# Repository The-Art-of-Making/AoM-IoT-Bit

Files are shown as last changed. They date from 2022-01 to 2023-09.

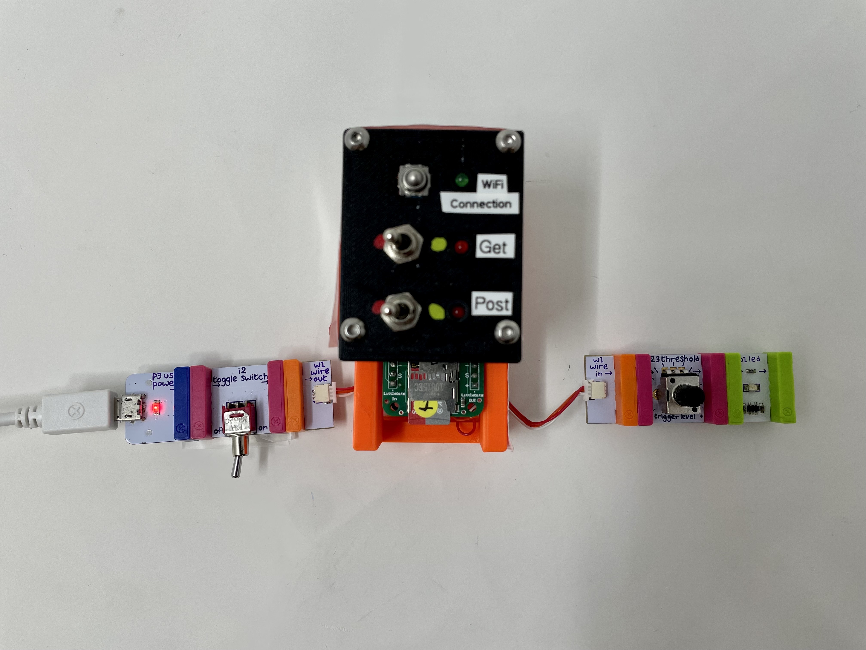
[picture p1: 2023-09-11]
Diagrams/quick-start-guide_circuit.jpg

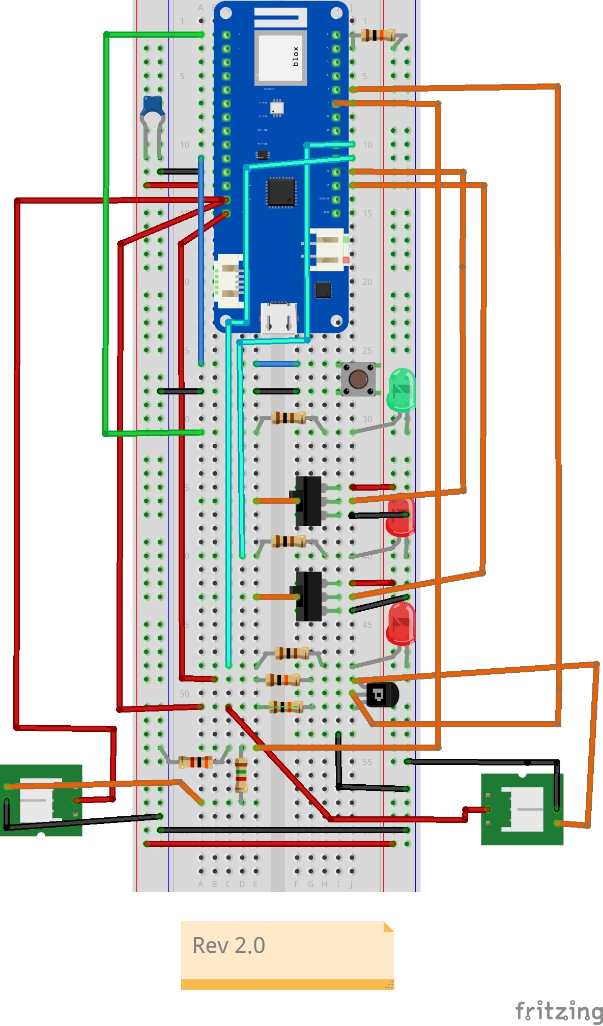
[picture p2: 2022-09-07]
Fritzing-Schematics-PCB/AOM_IoT_Bit_V3.0_breadboard.jpg

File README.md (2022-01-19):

# AOM IoT Bit - Spring 2022
------------------------------------

## Summary
------------------------------------
The AOM IoT Bit, is a device that allows students to prototype with IoT, without the overhead of all the logistics that come with setup.

The goal is that students will be able to **easily link an AOM IoT Bit to a LittleBits circuit, and get that circuit to send and/or recieve data through a cloud-based system**.

**\*\*Insert Image Here\*\***

------------------------------------
## Usage of a fully setup AOM IoT Bit
------------------------------------
To Use the AOM IoT Bit, all a student needs to do is the following:

- Open up a serial connection and ... add their credentials to the arduino_secrets_mine.h file ***[DO NOT SHARE THIS!]***

- Push the code to the MKR 1010 Arduino Board.

- Plug it in to their LittleBits circuit, and set the onboard switch to the proper setting (Push, Poll, Both)

------------------------------------
## Building an AOM IoT Bit
------------------------------------
We have started by using the Arduino MKR 1010 Board, Found Here:
**\*\*Insert Build Instructions Here\*\***

------------------------------------
## Initial Setup of an AOM IoT Bit
------------------------------------
**\*\*Insert Setup Instructions Here\*\***

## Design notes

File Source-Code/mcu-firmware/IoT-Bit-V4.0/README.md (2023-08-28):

# IoT-Bit-V4.0 Firmware

Arduino-based firmware for connecting the IoT Bit to an MQTT server.

Target board: Arduino MKR WiFi 1010

## Overview

1. Wifi and MQTT authentication credentials are read from the SD card.
2. The Bit connects to Wifi.
3. If a Wifi connection is established, the Bit then tries to connect to a MQTT server, authenticate, and subscribe to the `config` and `cmd` topics corresponding to its devices.
4. The Bit configures its devices based on the configuration received on the `config` topics. Configurations information is stored in protocol buffers sent in the payload of MQTT messages published to the `config` topics.
5. The Bit publishes messages with the value of its input devices to the `state` topics whenever the values of the input devices change. The Bit also updates its output devices whenever it receives a message with an updated output value on the `cmd` topics.

## Prerequisites

1. Arduino `WiFiNINA` and `Ethernet` libraries

2. PubSubClient library for Arduino

   See [https://github.com/knolleary/pubsubclient](https://github.com/knolleary/pubsubclient)

3. nanopb and protoc (Optional)

   The `compile_protobufs.sh` script found in the `Source-Code/Backend/protobufs` directory can be used to automatically compile the necessary proto files. While technically only nanopb (which ships with this respository) is needed to generate the C implementation of the protocol buffers used in the firmware, the script generates the implementations for both C and python, and therefore also depends on protoc to run correctly in its current form. If you do not wish to install protoc or wish to compile the proto files manually, you may do so solely with nanopb.

## Build

1. Compile the proto files found in `Source-Code/Backend/protobufs` using nanopb
2. Open `IoT-Bit-V4.0.ino` in the Arduino IDE
3. Connect the IoT Bit and select the correct Board (Arduino MKR WiFi 1010) and Port
4. Click the "Upload" button to compile the firmware and upload it to the board

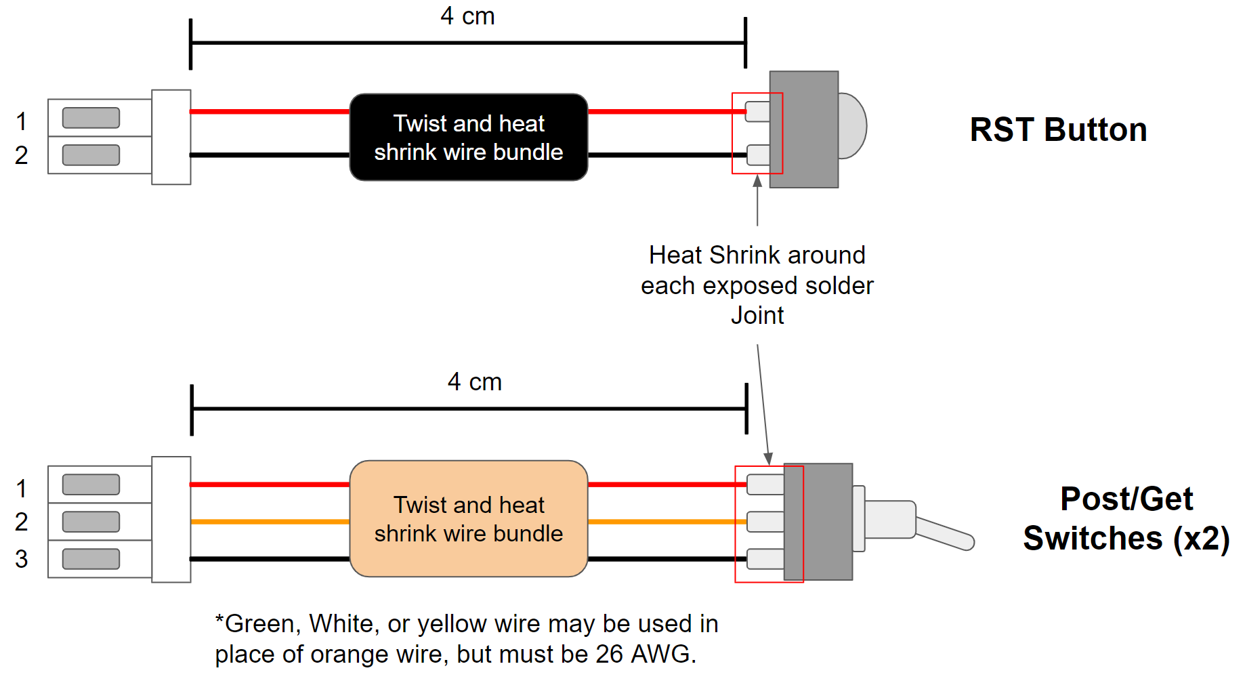
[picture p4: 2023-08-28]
media/REV_3/cable-diagram_button-switch.png

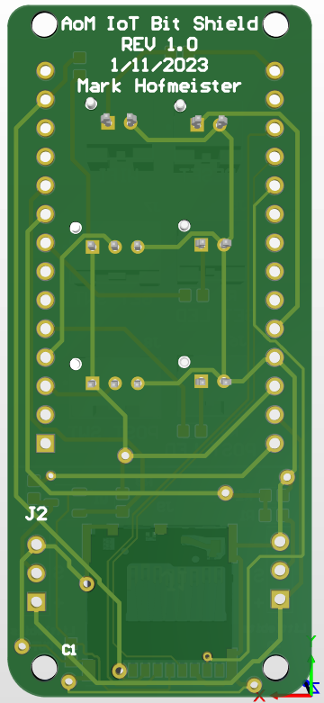
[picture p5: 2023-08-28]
media/REV_3/pcb-v1-bottom.png

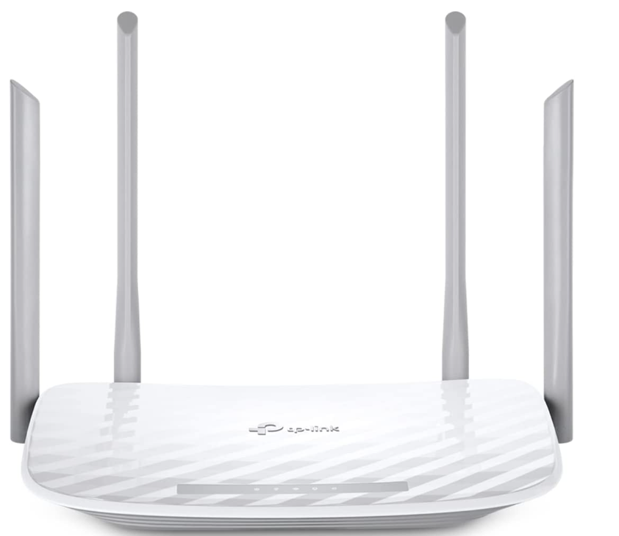
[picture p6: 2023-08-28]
media/REV_3/router.png

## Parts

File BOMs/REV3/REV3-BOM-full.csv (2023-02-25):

Name/Desc | MFR | MFR P/N | QTY | Vendor Link
Arduino MKR WiFi 1010 | Arduino | ABX00023 | 1 | https://store-usa.arduino.cc/products/arduino-mkr-wifi-1010
SD, LED, Switch PCB Shield | JLCPCB | - | 1 | https://jlcpcb.com/
Littlebits Wire | Sphero | 650-0071 | 1 | https://sphero.com/products/wire-bit
1x14 male headers | Lystaii | - | 2 | https://www.amazon.com/dp/B06ZZN8L9S
1x3 male headers | Lystaii | - | 2 | https://www.amazon.com/dp/B06ZZN8L9S
JST PA 2POS Male connector, TH | JST | B02B-PASK(LF)(SN) | 4 | https://www.digikey.com/en/products/detail/jst-sales-america-inc/B02B-PASK-1-LF-SN/926738
JST PA 2POS Female connector, TH | JST | PAP-02V-S | 4 | https://www.digikey.com/en/products/detail/jst-sales-america-inc/PAP-02V-S/759974
JST PA 3POS Male connector, TH | JST | B03B-PASK-1(LF)(SN) | 2 | https://www.digikey.com/en/products/detail/jst-sales-america-inc/B03B-PASK-1-LF-SN/926739
JST PA 3POS Female connector, TH | JST | PAP-03V-S | 2 | https://www.digikey.com/en/products/detail/jst-sales-america-inc/PAP-03V-S/759975
JST PA Crimps | JST | SPHD-002T-P0.5 | 14 | https://www.digikey.com/en/products/detail/jst-sales-america-inc/SPHD-002T-P0-5/608754
Red LED, 3mm | Adafruit | 777 | 2 | https://www.adafruit.com/product/777
Green LED, 3mm | Adafruit | 779 | 1 | https://www.adafruit.com/product/779
Metal tactile switch | Adafruit | 3347 | 1 | https://www.adafruit.com/product/3347
Plastic Beveled LED Holders | Adafruit | 2179 | 4 | https://www.adafruit.com/product/2179
SPDT Toggle Switch, Panel Mount | Adafruit | 3221 | 2 | https://www.adafruit.com/product/3221
M3 Knurled Threaded Inserts | SAVITA | - | 4 | https://www.amazon.com/dp/B0BMVHYGWM
M3 x 8mm Machine Screws | PZRT | - | 4 | https://www.amazon.com/dp/B07F6YGHKP
26 AWG Wire, Stranded Core, Red | OMEGA | 1569-26-1-0500-004-1-TS | 6 | https://www.digikey.com/en/products/detail/cnc-tech/1569-26-1-0500-004-1-TS/15853684
26 AWG Wire, Stranded Core, Black | OMEGA | 1569-26-1-0500-001-1-TS | 6 | https://www.digikey.com/en/products/detail/cnc-tech/1569-26-1-0500-001-1-TS/15853661
26 AWG Wire, Stranded Core, Yellow | OMEGA | 1569-26-1-0500-003-1-TS | 2 | https://www.digikey.com/en/products/detail/cnc-tech/1569-26-1-0500-003-1-TS/15853701
Heat shrink, red | - | - | 6 | -
Heat shrink, black | - | - | 6 | -
Heat shrink, yellow | - | - | 2 | -
microSD card, 8GB | Gigastone | - | 1 | https://www.amazon.com/dp/B0876H387X/
Paper-printed Decals, QR Code | - | - | 1 | -

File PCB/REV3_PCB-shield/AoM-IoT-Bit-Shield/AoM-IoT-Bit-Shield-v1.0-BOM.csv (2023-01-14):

Comment | Designator | Footprint | JLCPCB Part #?optional?
100 | R5,R7,R8 | 603 | C22775
10k | R3,R4,R6 | 603 | C25804
4.7k | R1 | 603 | C23162
9.1k | R2 | 603 | C23260
npn SOT-23-3 | Q1 | SOT-23-3 | C8512
sd slot | J9 | SMD | C428492
10uF | C1 | 603 | C19702

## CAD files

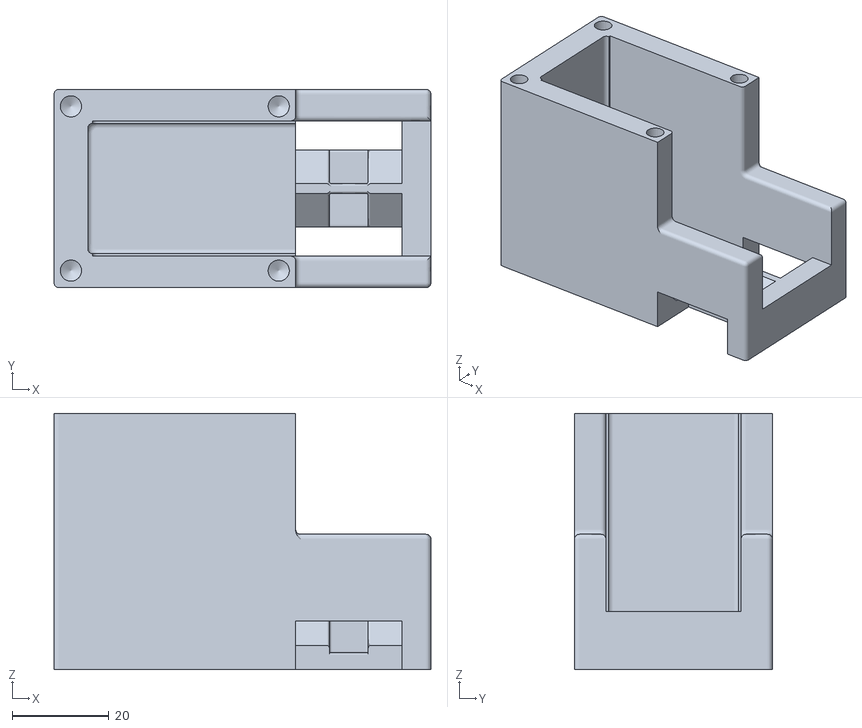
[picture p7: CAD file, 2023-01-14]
CAD/Base-Plate-v6.stl
78.0 x 41.0 x 53.0

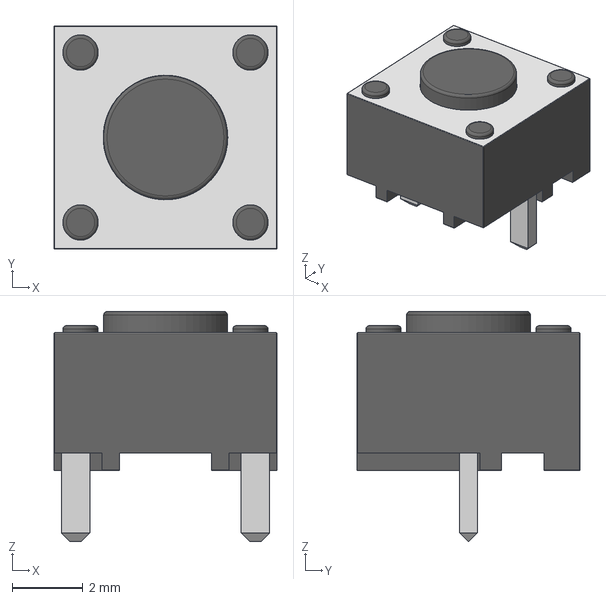
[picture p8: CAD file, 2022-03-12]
CAD/imported/Button black standard.STEP
6.30 x 6.30 x 6.50 mm

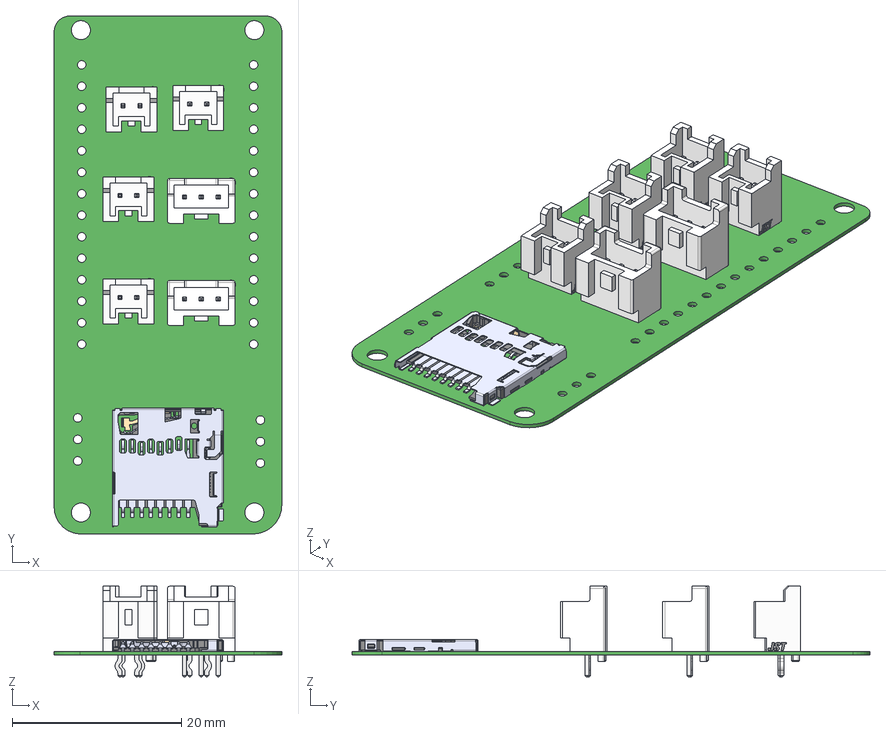
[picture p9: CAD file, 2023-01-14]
PCB/REV3_PCB-shield/AoM-IoT-Bit-Shield/AoM-IoT-Bit-Shield-v1.0.step
26.9 x 61.2 x 10.7 mm
B03B-PASK-1 x 2
JST Logo adjustable x 2
B02B-PASK-1 x 4

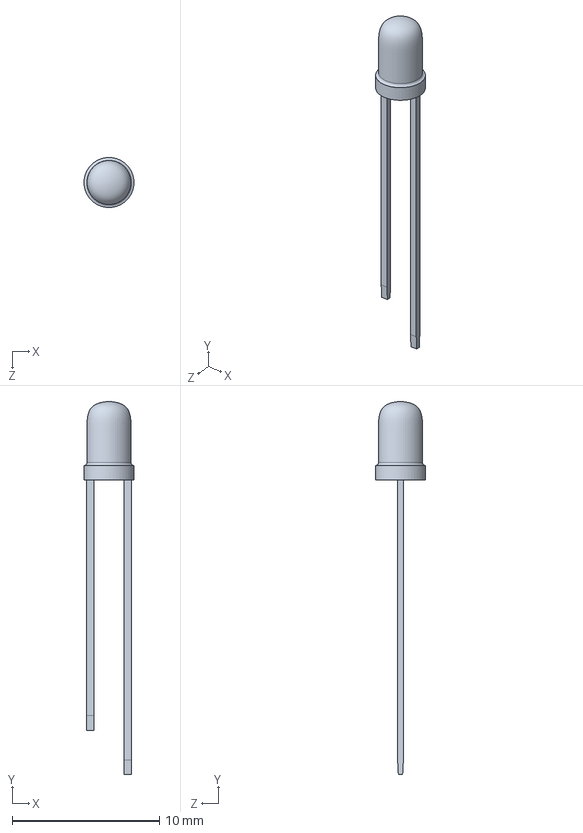
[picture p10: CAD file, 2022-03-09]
CAD/imported/redLED.SLDPRT
3.40 x 25.4 x 3.40 mm

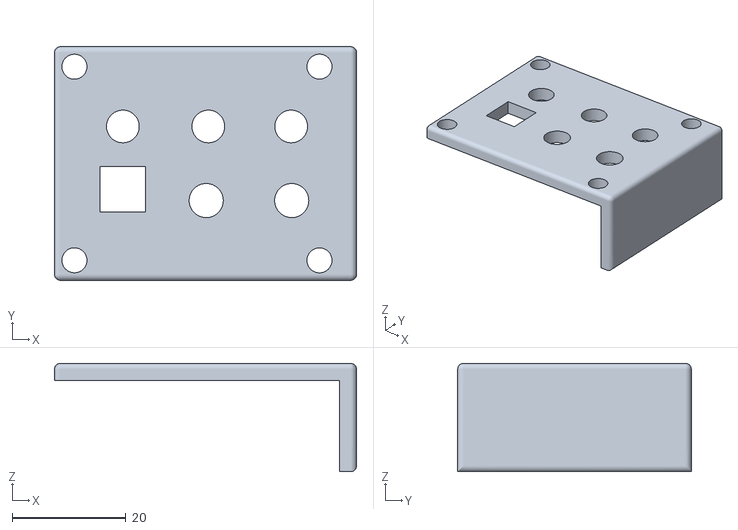
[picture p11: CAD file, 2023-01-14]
CAD/Top-plate-v7.stl
53.0 x 41.0 x 19.0

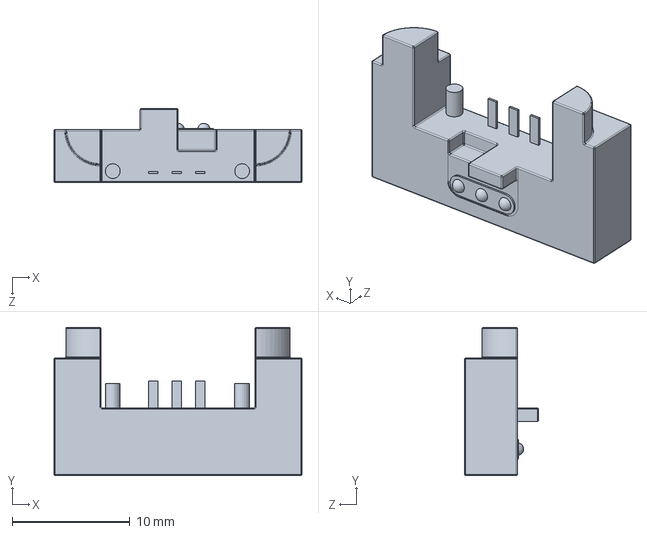
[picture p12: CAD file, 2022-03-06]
CAD/imported/Bit_1.SLDPRT
21.1 x 12.6 x 6.30 mm

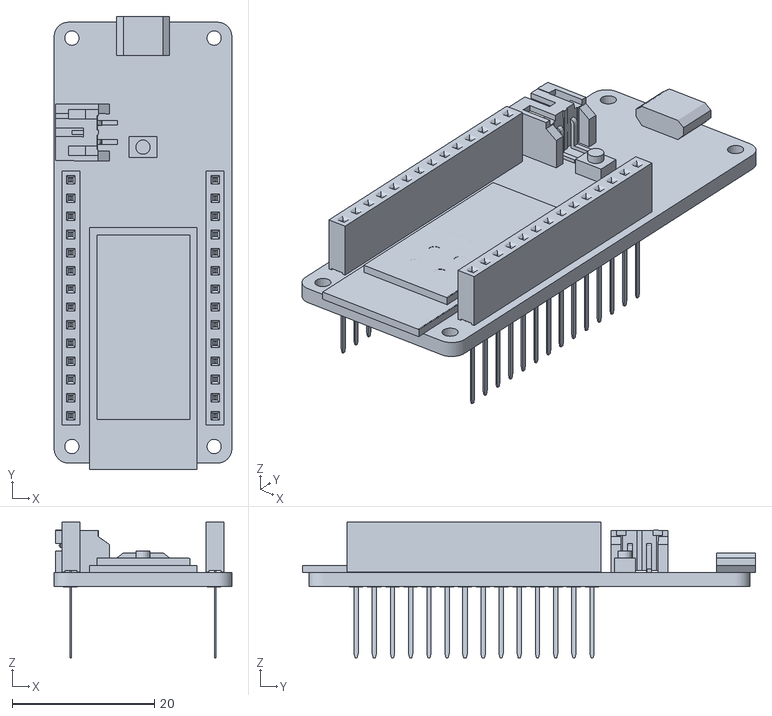
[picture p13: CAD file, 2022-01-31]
CAD/imported/Arduino_MKR_1000_long_pins.stl
25.0 x 63.7 x 19.1

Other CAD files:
CAD/imported/blueLED.SLDPRT
CAD/imported/Vertical slide switch SS-12D00G3 High Knob 3mm SPDT v2.f3d

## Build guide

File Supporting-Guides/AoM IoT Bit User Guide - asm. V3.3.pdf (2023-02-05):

# AoM IoT Bit User Guide

Author: Mark Hofmeister, (716) 261-0079, mah473@pitt.edu

Assembly v2.1, Electronics v2.1, Code v3.2

Last modified: 1/31/2023

You’ve just picked up one of the most sophisticated and useful LittleBits in the AoM repository of snap electronics. You’ve made a fantastic decision. This is the opportunity of a lifetime – and this video will show you why. (https://www.youtube.com/watch?v=zpKmXY5P1bY) Below will detail how to make the IoT bit come to life and a few basic example applications.

The IoT bit can either upload (“post”) or download (“get”) digital values from a cloud on the web. This means that it will be posting/getting values that are either HIGH or LOW, i.e. ON or OFF. This means that the Littlebits that you connect to the IoT Bit should be operated digitally. For example, you will be able to turn an LED ON or OFF with IoT bit. You will not, however, be able to adjust the brightness of the LED with a PWM signal. This means that you may need to make use of the “threshold” (https://classroom.littlebits.com/bit-o-pedia/threshold) and “latch” (https://classroom.littlebits.com/bit-o-pedia/latch) to digitize analog signals, which can be explored both through the links and through hands-on experimentation.

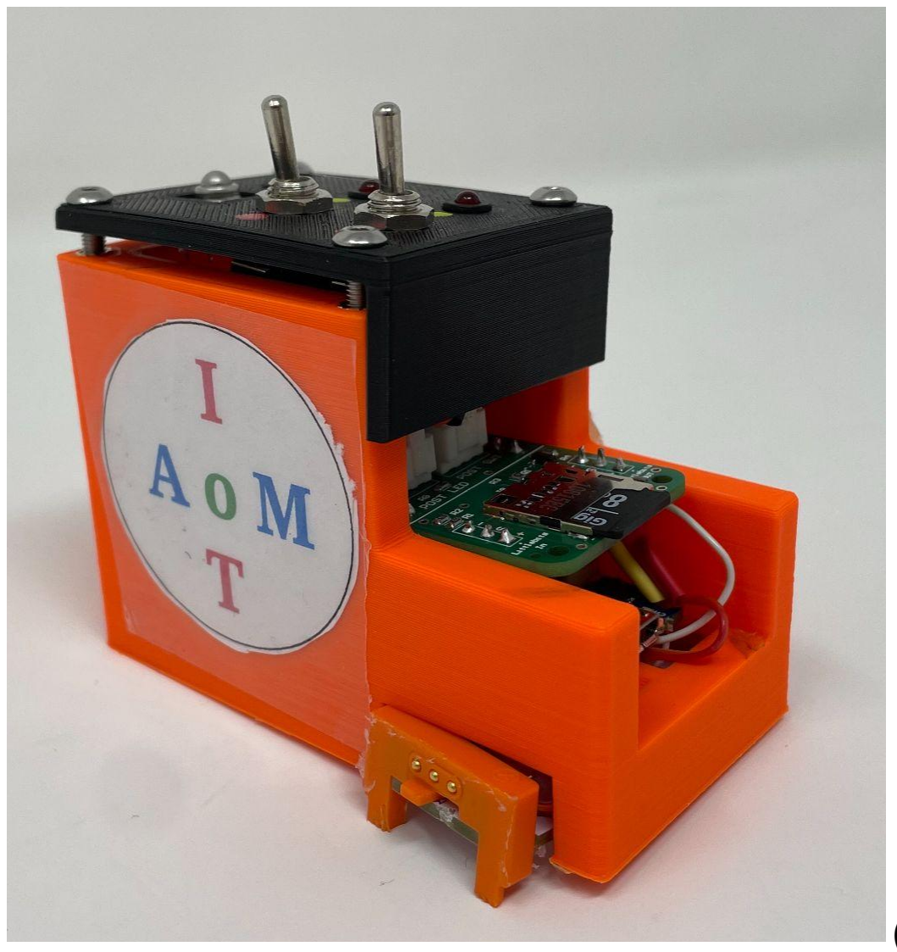
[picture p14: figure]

(Color may vary)

ENGR 0716/1716 The Art of Making: Hands-On System Design and Engineering • Version 3.2 | 1

## Table of Contents

## How Do I Use this Thing? How Do I Connect to IFTTT? Changing WiFi Credentials Windows Users Mac Users Changing an IoT Bit’s Feed Windows Users Mac Users “Hello, World” Applications 1. Post to IO 2. Get from IO Advanced Settings Using a different Adafruit IO+ account

ENGR 0716/1716 The Art of Making: Hands-On System Design and Engineering • Version 3.2 | 2

## How Do I Use this Thing?

Good question.

## Here’s a diagram of the interface’s functionality:

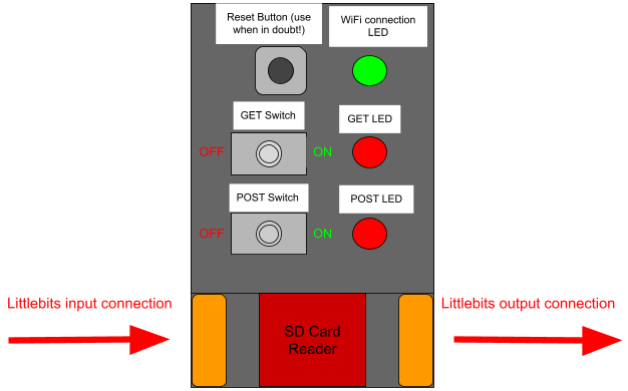
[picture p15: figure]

When you snap your IoT bit in series with (powered) Littlebits, you’ll see the IoT bit configure itself through these steps:
1. All 3 LEDs will blink 3 times quickly - This indicates that the IoT bit is going to attempt to read from the SD card. This flashing will repeat every ~3 seconds until the IoT Bit reads the SD card’s data successfully. If the flashing keeps repeating, make sure the SD card is seated in the SD card reader properly.
2. All 3 LEDs will blink for a full second - This indicates that the IoT bit has successfully read from the SD card and is ready to connect to the cloud.
3. The Green LED illuminates (and stays illuminated) - This indicates a successful WiFi connection. Be patient when connecting to WiFi - a secure connection can take ~10 seconds to establish.
ENGR 0716/1716 The Art of Making: Hands-On System Design and Engineering • Version 3.2 | 3

4. From here, the IoT bit will enter a loop depending on the state of the switches. Below are the 4 operations:
a. No switches are turned on - IoT Bit will remain idle and do nothing.
b. The GET Switch is turned on - The IoT Bit will “get” the latest value from the cloud. If the latest value in the cloud is “HIGH,” the IoT bit will output a HIGH electrical signal. If the latest value in the cloud is “LOW,” the IoT bit will output a LOW electrical signal.
c. The POST Switch is turned on - If the IoT Bit detects a change in the state of the digital input signal, it will “post” it to the cloud. If the IoT Bit’s electrical input signal value changes to “HIGH,” the IoT bit will post a HIGH value to the cloud. If the IoT Bit’s electrical input signal value changes to “LOW,” the IoT bit will post a LOW value to the cloud.
d. The GET switch and POST switch are both turned on - the IoT bit will both POST a changing incoming signal to Adafruit IO and GET the signal back from the cloud. Use this if you want to upload a value to the cloud as well as send that signal through the IoT bit to sequential LittleBits.
5. Log in to the AoM Cloud (https://io.adafruit.com/aom_cloud/feeds) and select the feed that your IoT Bit is connected to to view the latest data!
AoM Cloud Username: aom_cloud
AoM Cloud Password: designthinking

Do not hit “regenerate key” in Adafruit IO - this will change the access code and all IoT Bits will have to be reconfigured.

Again, be patient when connecting to WiFi - a secure connection (indicated by the illuminated green LED on the IoT Bit) can take ~10 seconds to establish.

ENGR 0716/1716 The Art of Making: Hands-On System Design and Engineering • Version 3.2 | 4

## How Do I Connect to IFTTT?

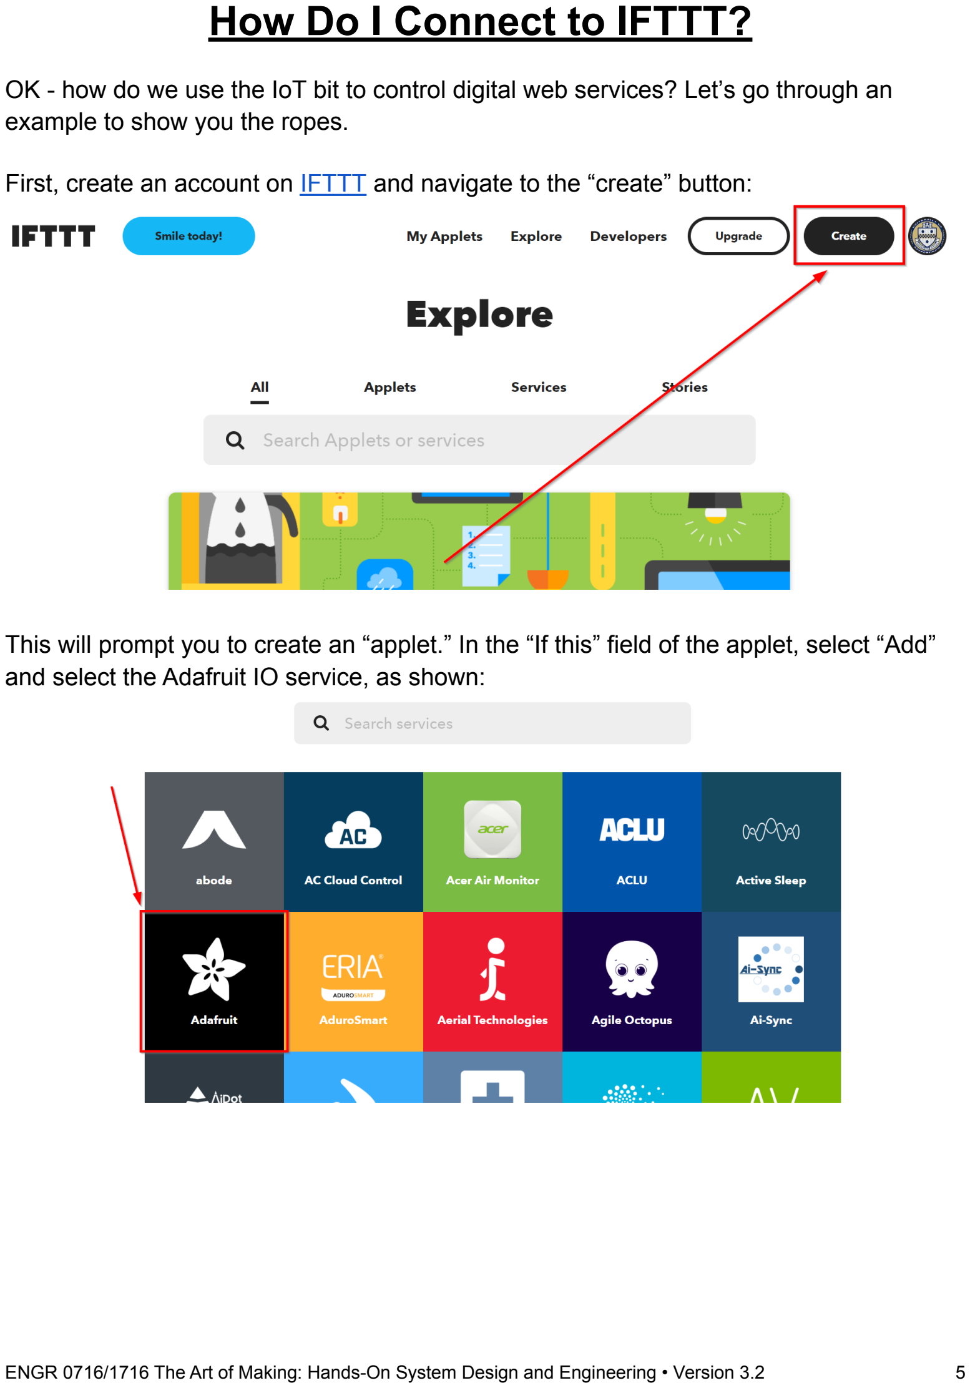
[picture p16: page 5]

OK - how do we use the IoT bit to control digital web services? Let’s go through an example to show you the ropes.

First, create an account on IFTTT (https://ifttt.com/join) and navigate to the “create” button:

This will prompt you to create an “applet.” In the “If this” field of the applet, select “Add” and select the Adafruit IO service, as shown:

ENGR 0716/1716 The Art of Making: Hands-On System Design and Engineering • Version 3.2 | 5

Authorize the sign-in prompt on IFTTT and select “Monitor a feed on Adafruit IO” as your trigger. Add the AoM Cloud’s Adafruit IO account name ( AoM IoT Bit,) AoM Cloud’s feed name (cloud - Feed {X}), set the relationship as “equal to,” and select “HIGH” as the value. This will trigger the “If this” portion of the widget any time the IoT bit uploads a HIGH value to Adafruit IO.

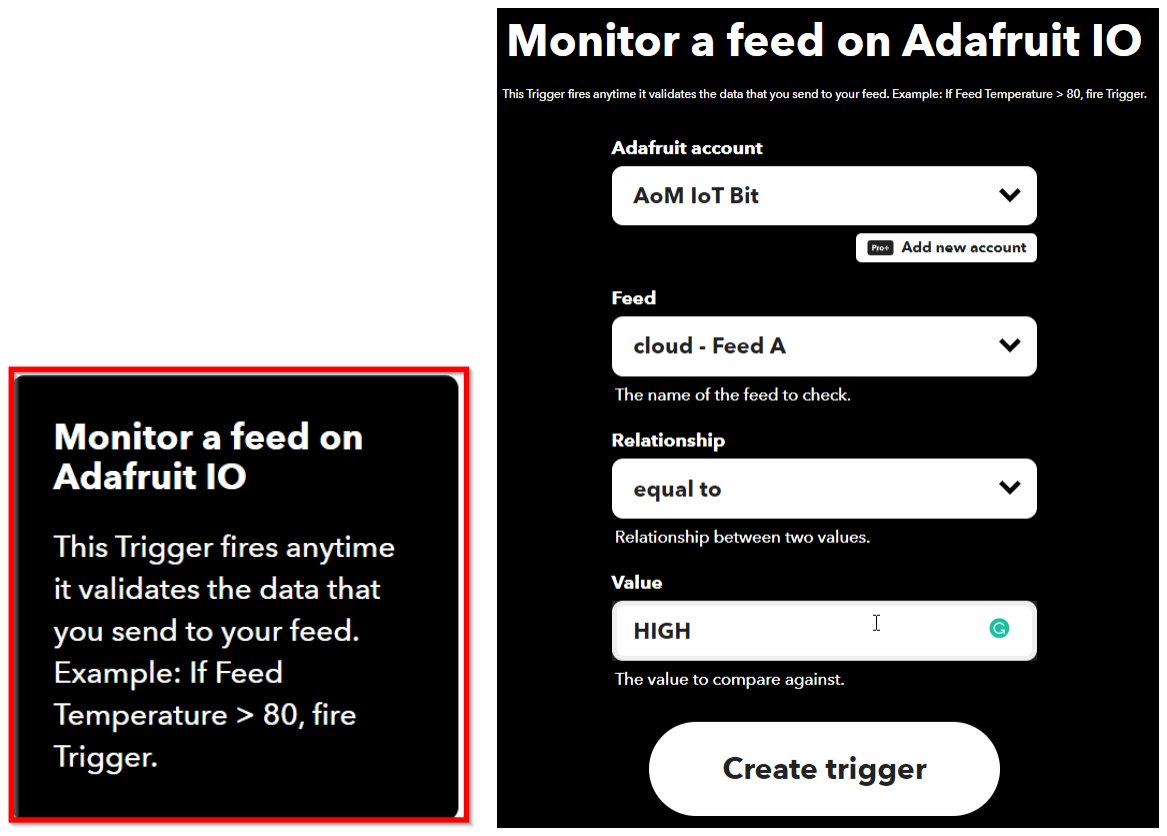
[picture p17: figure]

In the “Then That” field of the widget, select any web service that you want to interface to - it’s up to you! A simple “Hello World” test is the Google Tasks service, which allows you to create a task every time the Adafruit IO cloud receives a high value (i.e. IF Adafruit IO gets a high value, THEN create a Google Task.) But you’re only limited by your imagination - and the limits of the free IFTTT account, of course.

ENGR 0716/1716 The Art of Making: Hands-On System Design and Engineering • Version 3.2 | 6

## Changing WiFi Credentials

By default, IoT Bits connect to G34 WiFi. If you’d like to operate the IoT bit on a different WiFi network, you can configure which network the IoT Bit connects to. Keep in mind that you cannot connect to WIRELESS_PITTNET, so you’ll have to use another network
- mobile hotspots excel here.

## Windows Users

Remove the MicroSD card from the IoT Bit and connect it to your computer (via an adapter, if necessary. If you do not have an adapter, ask a TA for one.) Run the

program and disregard any warning messages from your PC (it’s safe - trust me.)

Select the | dropdown and hit the | button. You’ll be greeted with
this screen:

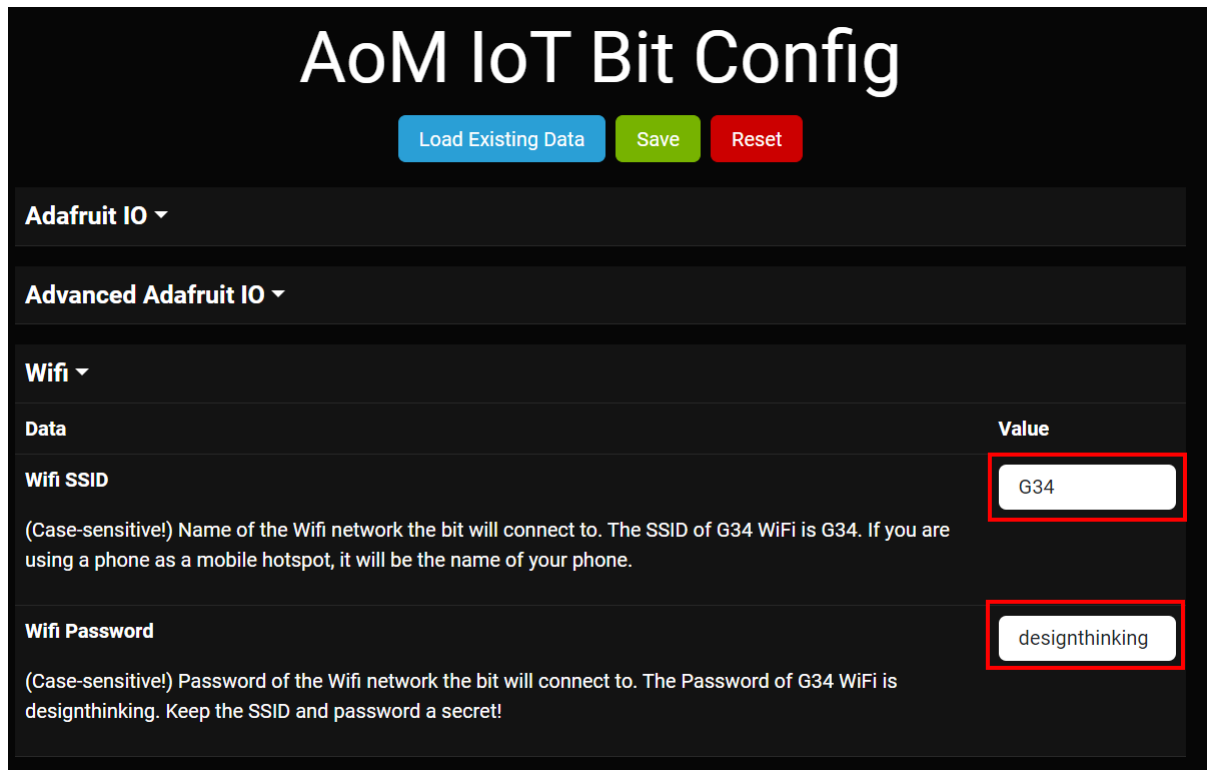
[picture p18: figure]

Enter in your WiFi credentials, hit the | button, and load the SD card back into
the IoT Bit. When you boot it back up, the IoT bit will indicate a successful WiFi connection with a green illuminated LED.
ENGR 0716/1716 The Art of Making: Hands-On System Design and Engineering • Version 3.2 | 7

Important: If you are using a mobile hotspot, be sure to turn on the “Maximize Compatibility” option in the hotspot configuration, or the IoT bit will not be able to connect. If you don’t have a “Maximize Compatibility” option, ignore this warning.

If you are having trouble connecting to a mobile hotspot, make sure that your mobile hotspot screen is pulled up on your phone.

ENGR 0716/1716 The Art of Making: Hands-On System Design and Engineering • Version 3.2 | 8

## Mac Users

Remove the MicroSD card from the IoT Bit and connect it to your computer (via an adapter, if necessary. If you do not have an adapter, ask a TA for one.) When you open the secrets.txt file on the SD card, you’ll see the contents of 7 variables, separated by semicolons. To change WiFi networks, you’ll modify the WiFi SSID and WiFi password variables, which default to G34 WiFi credentials:

Here’s what these variables mean:

WiFi SSID | The SSID of your WiFi network, i.e. the name. Defaults to G34. If you are using a phone as a mobile hotspot, it will be the name of your phone. Note that you cannot use WIRELESS_PITTNET as a WiFi network. If using a mobile hotspot, you may not have any special characters in the name of your device. For example, the apostrophe in “Samsher’s iPhone” will cause an error; you’ll have to change the name of your device.
WiFi Password | The password of your WiFi network/hotspot. Defaults to designthinking. Keep the SSID and password a secret!

Here’s an example of what a secrets.txt file might look like with your data replacing the WiFi variable names:

2;Samsher_Phone;Samsher1234;aom_cloud;cloud;feed-a;AoMIoKeYsEcReT123

Careful - These variables are case sensitive!

Important: If you are using a mobile hotspot, be sure to turn on the “Maximize Compatibility” option in the hotspot configuration, or the IoT bit will not be able to connect. If you don’t have a “Maximize Compatibility” option, ignore this warning.

ENGR 0716/1716 The Art of Making: Hands-On System Design and Engineering • Version 3.2 | 9

If you are having trouble connecting to a mobile hotspot, make sure that your mobile hotspot screen is pulled up on your phone. Be sure that your SSID (i.e., the name of your phone) does not have any apostrophes in it.

ENGR 0716/1716 The Art of Making: Hands-On System Design and Engineering • Version 3.2 | 10

## Changing an IoT Bit’s Feed

## Windows Users

Remove the MicroSD card from the IoT Bit and connect it to your computer (via an adapter, if necessary. If you do not have an adapter, ask a TA for one.) Run the

program and disregard any warning messages from your PC (it’s safe - trust me.)

Select the | and hit the | button. You’ll be greeted with this
screen:

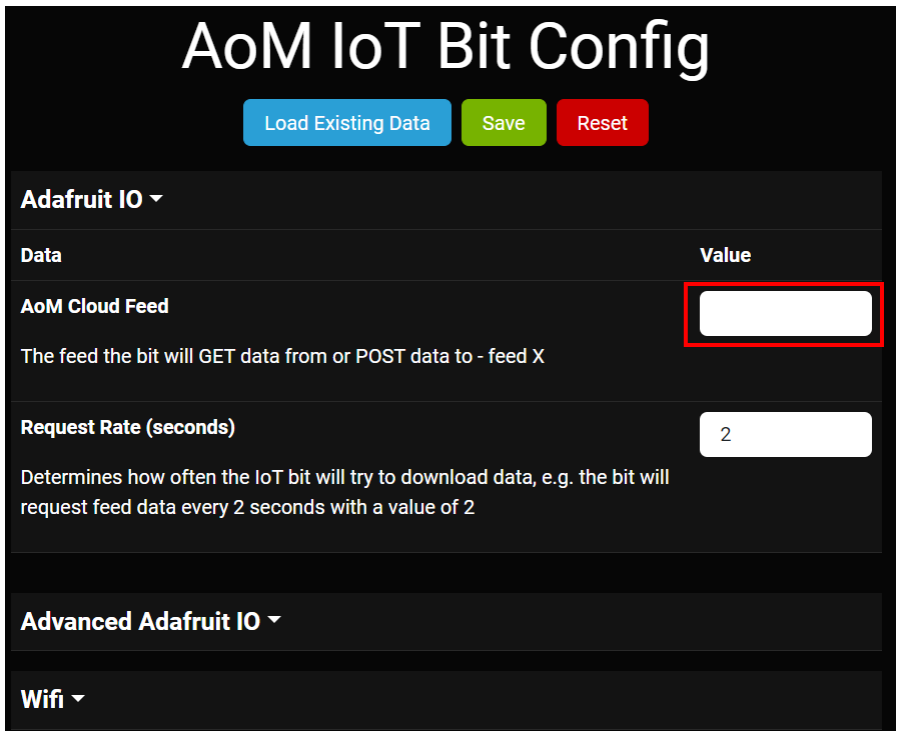
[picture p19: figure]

Enter in the feed that you’d like to connect your IoT Bit to (A-F), hit the | button,
and load the SD card back into the IoT Bit.
ENGR 0716/1716 The Art of Making: Hands-On System Design and Engineering • Version 3.2 | 11

## Mac Users

Remove the MicroSD card from the IoT Bit and connect it to your computer (via an adapter, if necessary. If you do not have an adapter, ask a TA for one.) When you open the secrets.txt file on the SD card, you’ll see the contents of 7 variables, separated by semicolons. To change feeds, you’ll modify the feed name credential.

Here’s an example of what a secrets.txt file might look like after changing from feed A to feed B.

2;G34;designthinking;aom_cloud;cloud;feed-b;AoMIoKeYsEcReT123

Careful - These variables are case sensitive. Even though the feeds are named with capital letters, the name should be entered as a lowercase

ENGR 0716/1716 The Art of Making: Hands-On System Design and Engineering • Version 3.2 | 12

## “Hello, World” Applications

## 1. Post to IO

You will need:
- Littlebits p4 power bit (1)
- Littlebits toggle switch, flipped to the off position (1)
- Littlebits LED (1)
- AoM IoT Bit (1)
a. Build the circuit as shown below:

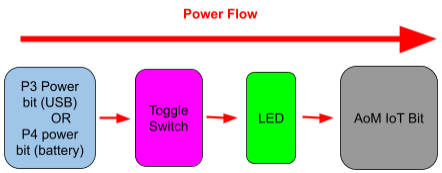
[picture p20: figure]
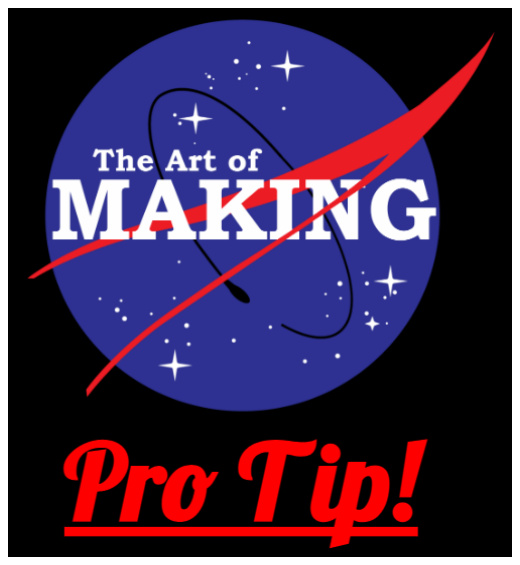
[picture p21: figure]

Scrub your Littlebits connections with a microfiber cloth to ensure a sound electrical connection and use littleBits magnetic shoes (https://sphero.com/products/shoes) or mounting boards (https://sphero.com/products/mounting-board) to keep the circuit from breaking connection and resetting.

b. Once the IoT Bit is powered and the green LED on the IoT Bit illuminates to indicate a WiFi connection, flip the “post” switch from left to right to the “ON” position.
c. Flip the Littlebits toggle switch state from off to on. The littlebits LED should illuminate, and the post LED will pulse to indicate a successful upload. Check the data stream on your Adafruit IO feed - you should see a new “HIGH” value uploaded to the feed. The IoT Bit will upload the IoT bit’s input signal to the cloud every time that input signal changes from LOW to HIGH or HIGH to LOW.
d. Alright! Now you can send data to the AoM cloud. Flip the “post” switch back to “OFF” before proceeding to “Hello, World” application 2.
ENGR 0716/1716 The Art of Making: Hands-On System Design and Engineering • Version 3.2 | 13

## 2. Get from IO

You will need:
- Littlebits p4 power bit (1)
- Littlebits LED (1)
- AoM IoT Bit (1)
a. Build the circuit as shown below:

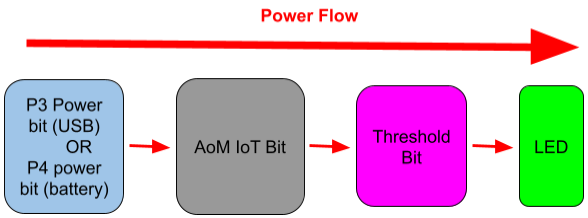
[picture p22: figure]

Dust your Littlebits connections with a microfiber cloth to ensure a sound electrical connection and use LittleBits magnetic shoes (https://sphero.com/products/shoes) to keep the circuit from breaking connection and resetting.

b. Once the IoT Bit is powered, flip the “get ” switch from left to right to the “ON” position. Turn the threshold bit knob to about ⅔ of maxed out.
c. Once the green LED on the IoT Bit illuminates to indicate a WiFi connection, the GET LED will begin to pulse, indicating that the output of the IoT bit is reflecting the data in the cloud - i.e. if the most recent data point in the cloud is HIGH, the IoT bit will output a HIGH signal. If the most recent data point in the cloud is LOW, the IoT bit will output a LOW signal. This behavior will dictate the state of the LittleBits LED.
ENGR 0716/1716 The Art of Making: Hands-On System Design and Engineering • Version 3.2 | 14

## Advanced Settings

## Using a different Adafruit IO+ account

You may want to use your own cloud instead of the AoM IoT Bit Cloud. To do this, create an account on Adafruit IO, (https://accounts.adafruit.com/users/sign_up) which is a web-based cloud service where the IoT bit will upload and download data from.

Once you create an account, navigate to the “IO” tab.

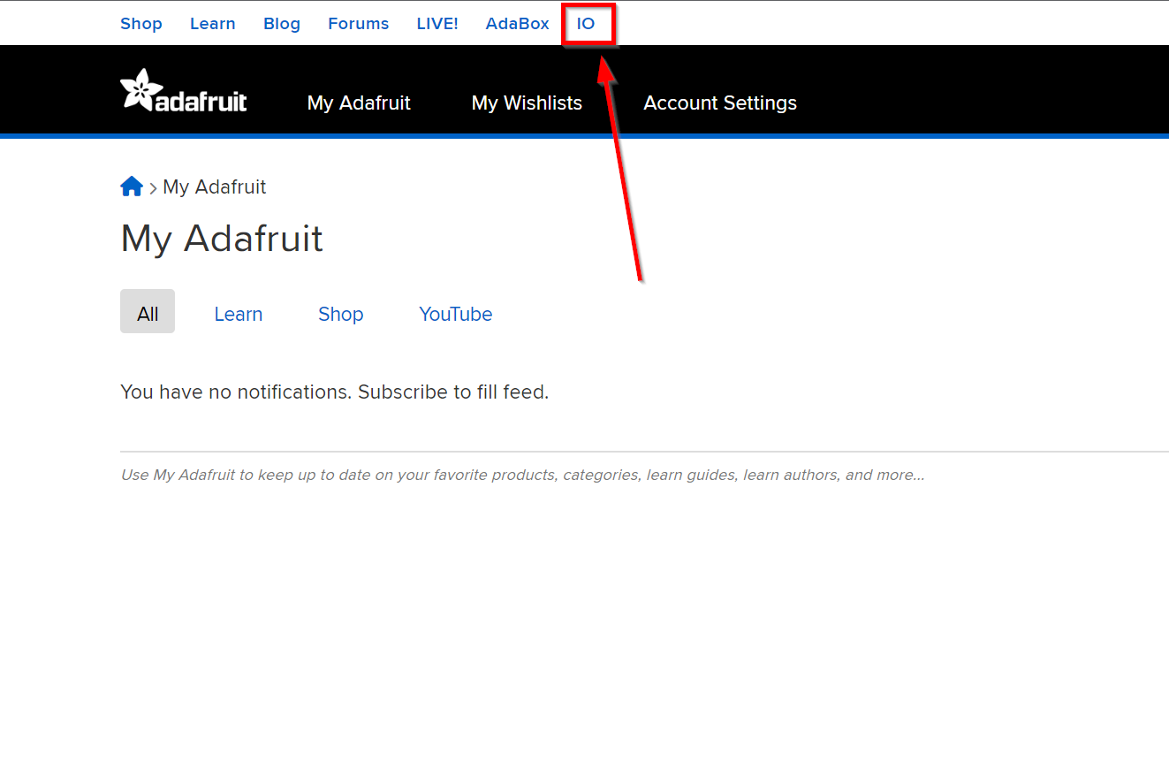
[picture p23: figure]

Next, navigate to the “Feeds” tab in IO.

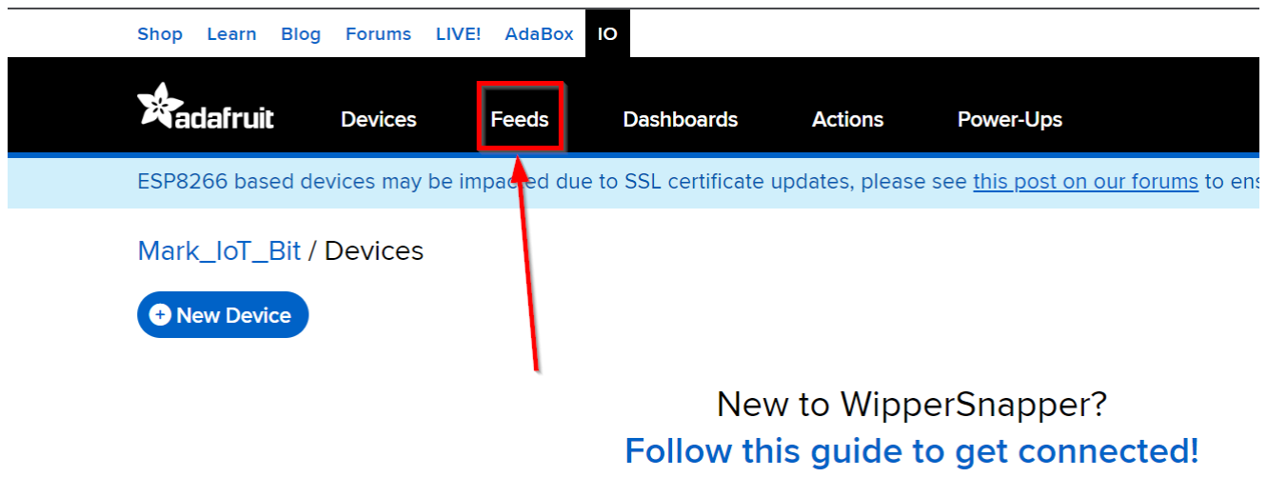
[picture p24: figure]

Next, Create a New feed by selecting the | button. “Feeds” are specific
places that the IoT Bit can send data to. Make sure to name your feed so that it corresponds to the data that you’ll be sending it. For example, if the feed will be
ENGR 0716/1716 The Art of Making: Hands-On System Design and Engineering • Version 3.2 | 15

receiving data about whether a button is on or off, you might name the feed “button_state.”

The feed will be empty because the IoT bit hasn’t uploaded any data to it yet. To get the

“ball rolling,” you can manually add data by pressing the | button. This isn’t
very useful to you right now, but it will be soon when we begin to construct circuits. You’ll also notice that the feed has a graph to show the history of values in the feed.

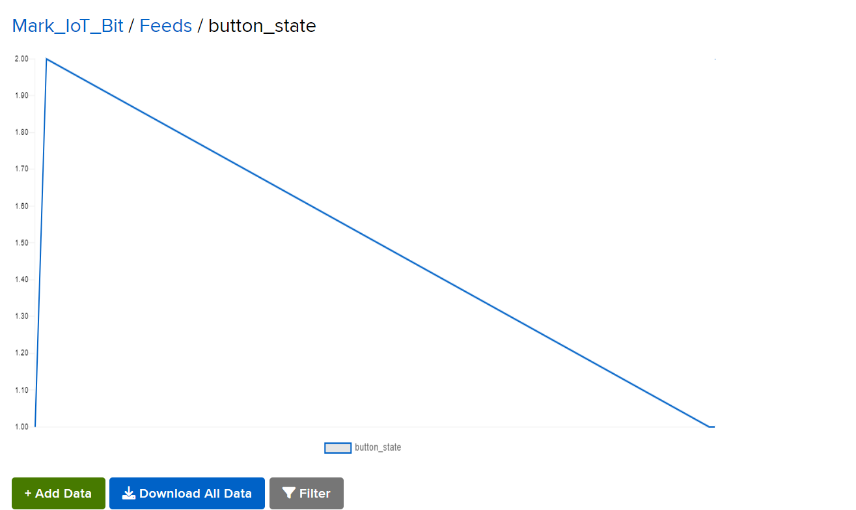
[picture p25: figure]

ENGR 0716/1716 The Art of Making: Hands-On System Design and Engineering • Version 3.2 | 16

You’ve (hopefully) mastered the very basics of the proprietary AoM IoT bit. If you’d like, be sure to copy and remove your credentials from the SD card before returning the IoT bit to the Littlebits wall. Congratulations - the control of an infinite number of objects is now possible with the flip of a switch, from anywhere that can connect to WiFi. Don’t let the power get to your head - but go out and make incredible devices. However, I simply must emphasize this once more:

This was created with design thinking and is a work in progress. The technology is snazzy and fancy, and that is all well and good, but what is most important is your experience. Which means that you should give us (honest!) user feedback -what works? What doesn’t? What’s awful? DON’T hesitate to reach out to me!

ENGR 0716/1716 The Art of Making: Hands-On System Design and Engineering • Version 3.2 | 17

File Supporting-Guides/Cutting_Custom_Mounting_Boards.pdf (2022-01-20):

# A copy of a post I made to our TAs last September to show how I'd cut a littleBits mounting board to create a mountable base for the "RedBot Amps" (constructing the RedBot Amps is what used up our supply of Proto Bits):

# RedBot Amps mounting boards -- some ideas!

I tried a few experiments this afternoon with the mounting boards for the littleAmps (aka RedBot Amps). Here are my results/thoughts, provided in an illustrated step-by-step guide inspired by Clara's earlier dowel holder post!

Here's the end result I think we're aiming for:

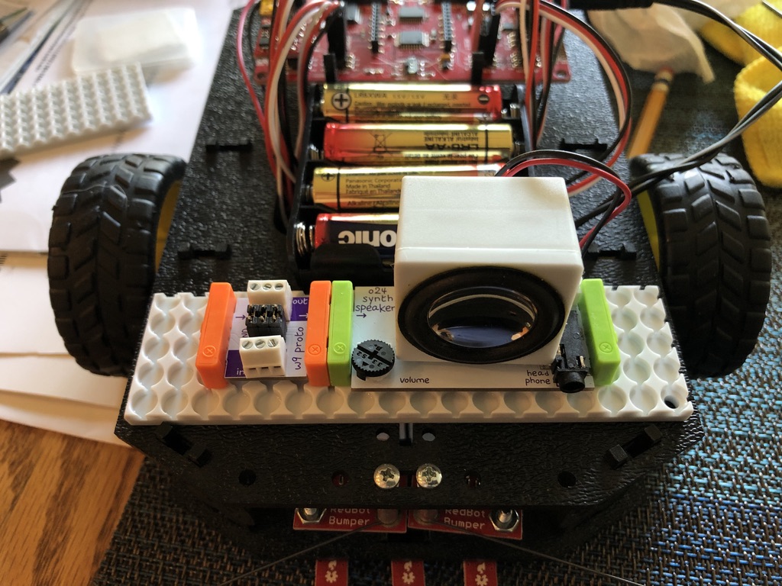
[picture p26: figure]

The size of the cut mounting board above provides a nearly ideal fit on the front of the top chassis plate of the RedBot --with "wings" on the sides where a couple of strips of tape could be placed to hold it in place during a vigorous performance!

Here are the cutting dimensions I used:

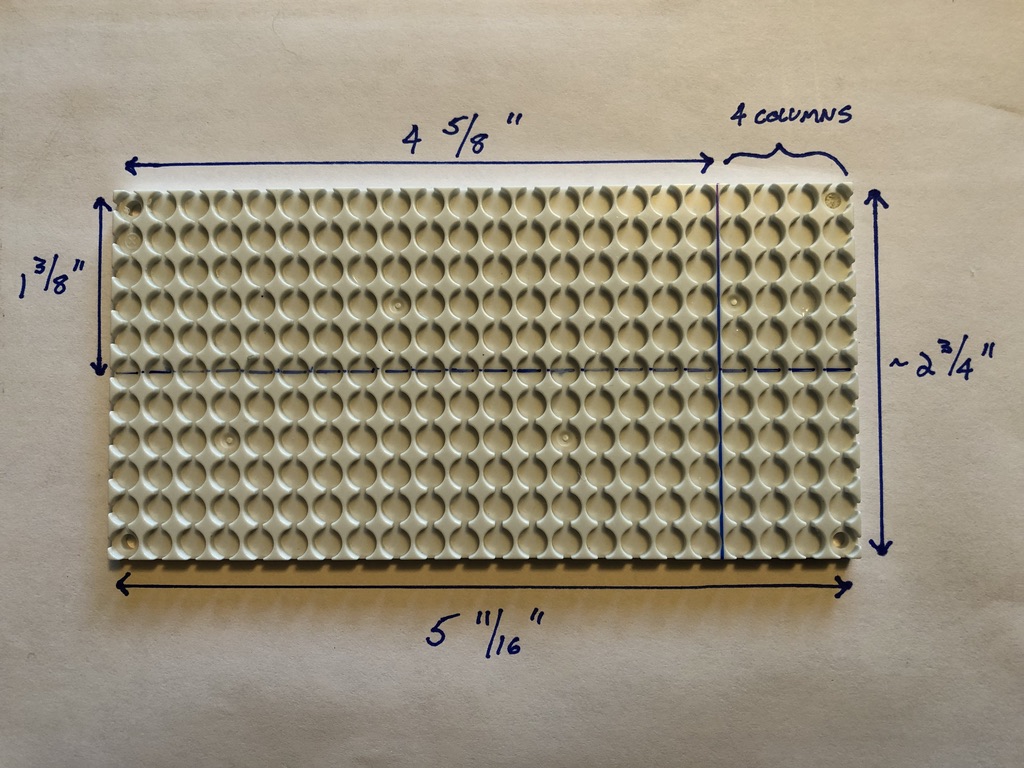
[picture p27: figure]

OK, those are the cutting dimensions I *should* have used. What I'll show below was my first attempt where I cut the board slightly asymmetrically so I had a "5 holes wide piece" and a "6 holes wide piece". I did this so I was cutting on a vertical "ridge" of the plastic -- but after doing this I realized it didn't really provide any benefit, and cutting so as to produce two "5.5 holes wide" pieces would have been just as good and results in two identical pieces.

How did I cut it? No fancy lasers or robots -- just a miter box and back saw like we have in G34. I cut across the short dimension first, cutting off "4 columns of holes" from the right side:

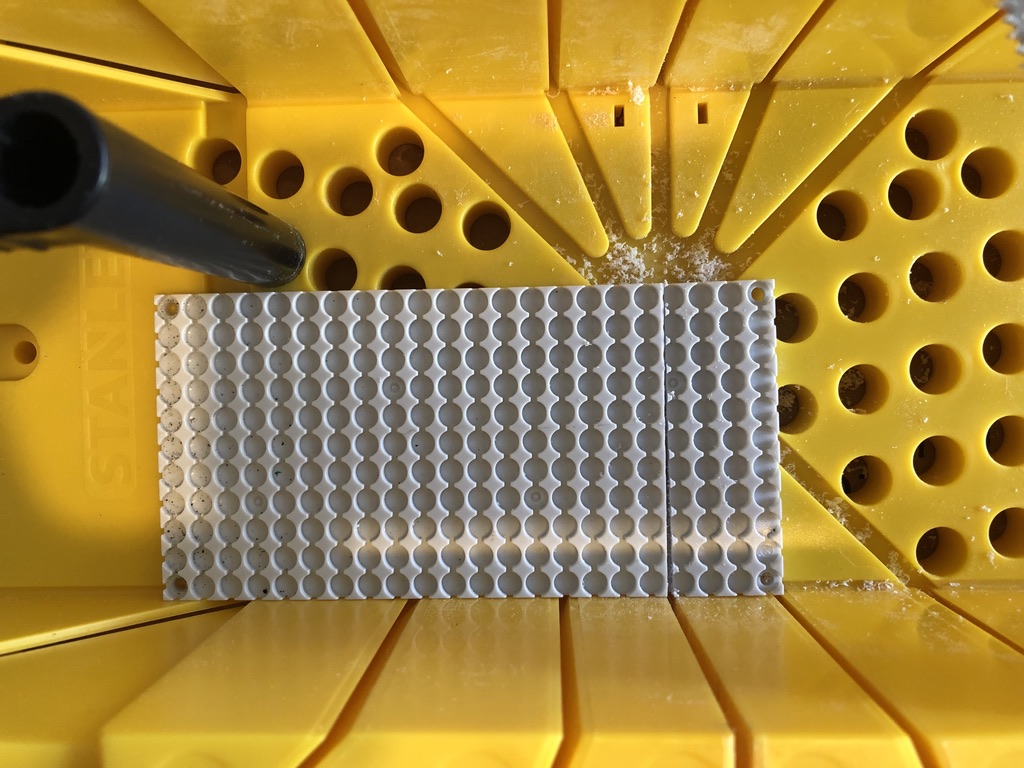
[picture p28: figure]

And then -- amazingly! -- the remaining long dimension exactly fit across the width of the box. Note: for both the first and second cuts, the pin clamps had to be turned in very carefully to avoid shifting the desired cutline off of the miter box sawline (required some "nudge and adjusting"):

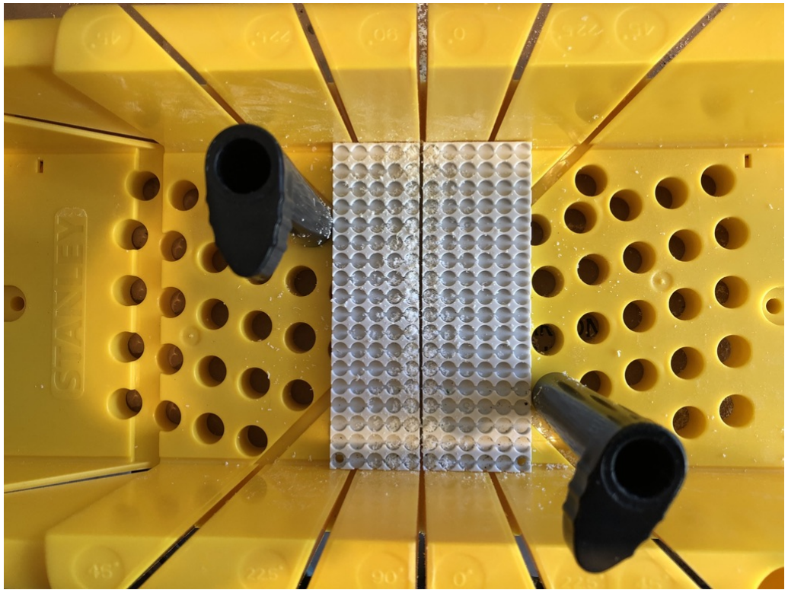
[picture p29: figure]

Again, I did a 5/6 cut above -- if I was doing over I'd just cut down the middle.

The cut edges had some plastic shards that were easily removed by (carefully) running an X-acto along the edge:

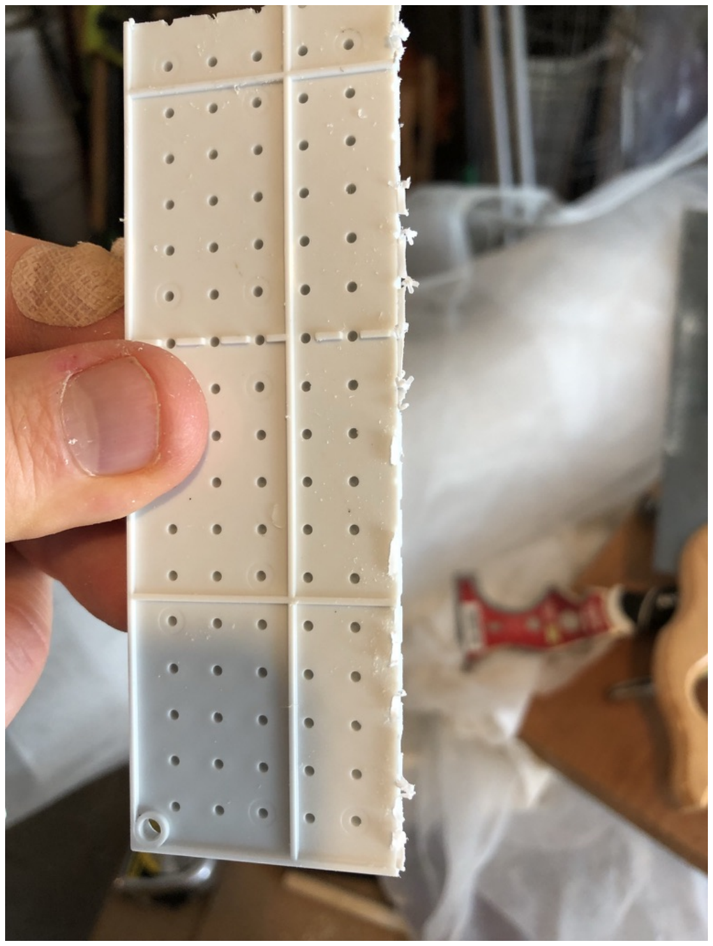
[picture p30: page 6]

(Note: bandaid on finger was not due to incompetence when using backsaw. It was due to incompetence two days ago while using kitchen knife.)

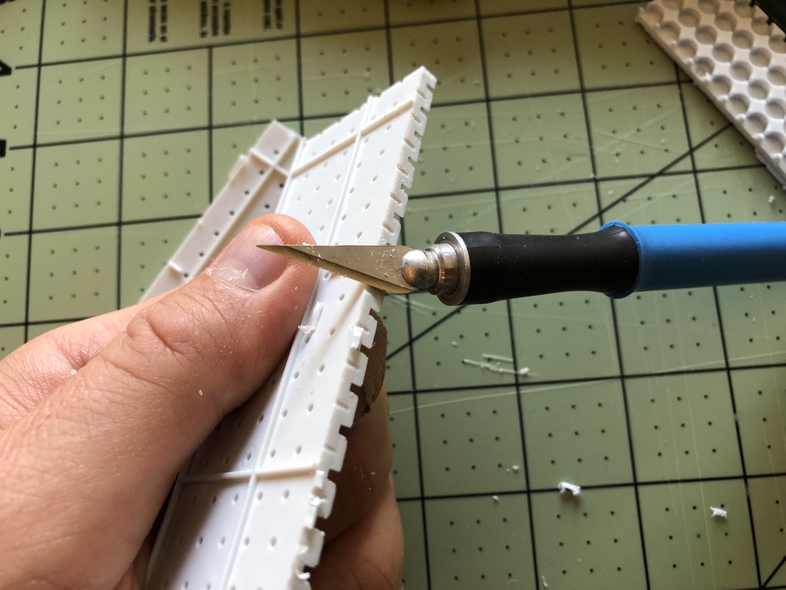
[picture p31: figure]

I then finished the edges with a few passes of fine (320) sandpaper:

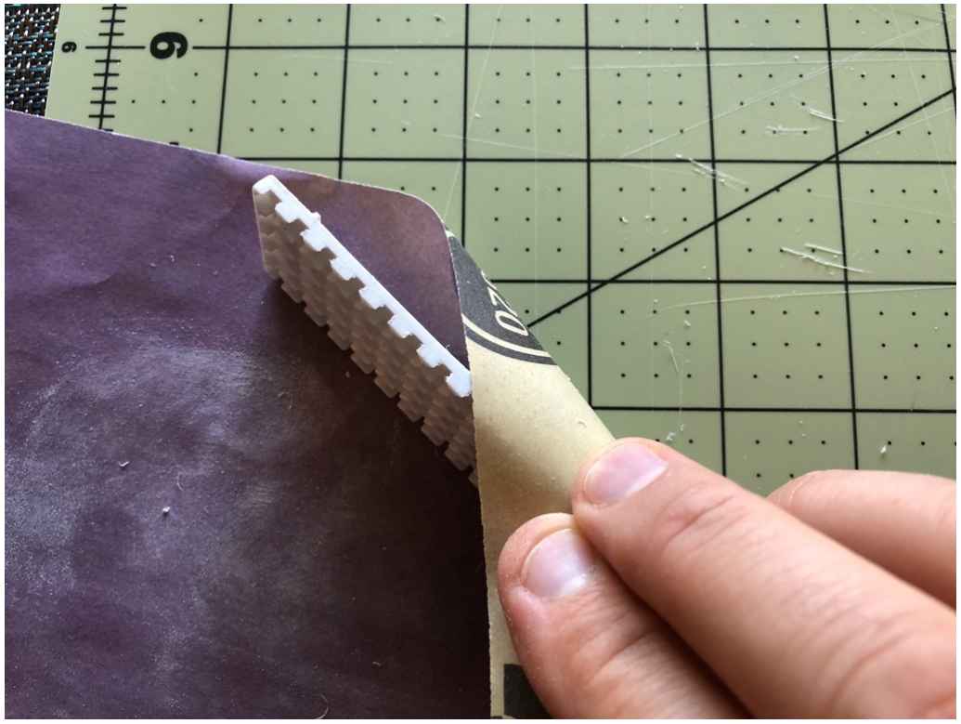
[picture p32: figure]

A note about littleBits mounting boards: there are at least two "flavors" I've run across, one is more "solid" (that's what I cut above), the other is more open. The solid one seems a little more rigid for mounting applications.

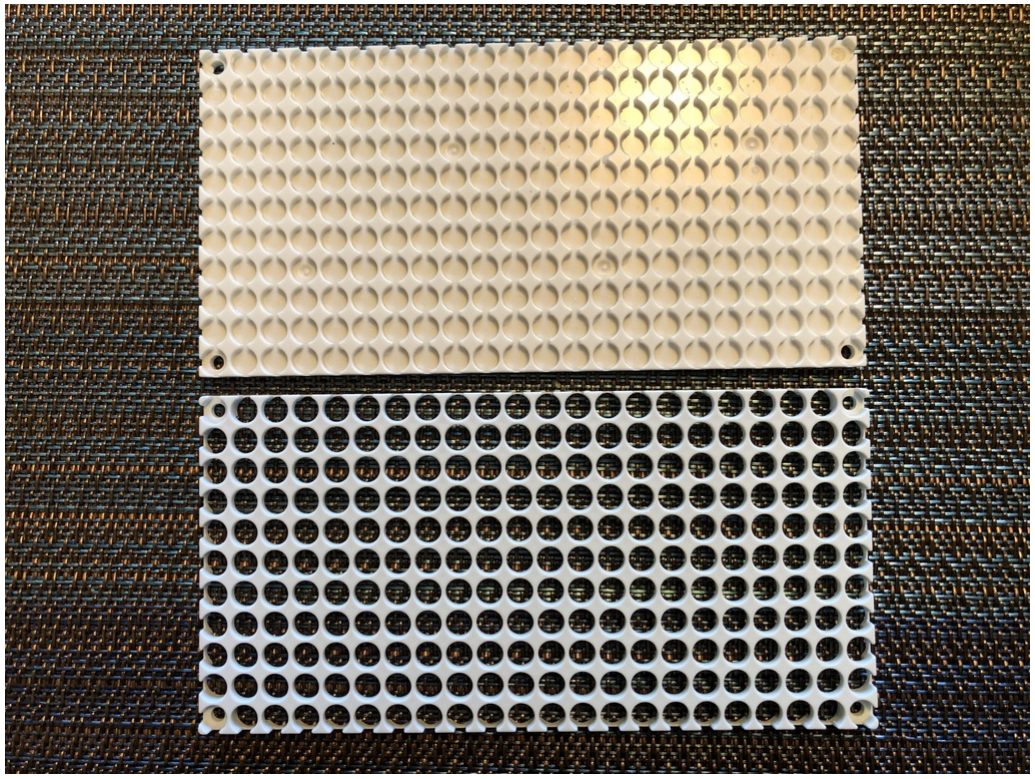
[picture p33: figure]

The total time it took for me to make the above two boards was about 10 minutes. So consider this as an option -- maybe we don't need CNC cutting.

And regarding laser cutting: I don't know for sure the identity of this plastic. It's too soft to be polycarbonate. When I sawed it the slight odor reminded me of cutting PVC -- it "feels" a little like that, but that's not a reliable way of identifying it. PVC should NOT be laser cut -- it works, but it generates hydrochloric acid and toxic fumes. So whatever we do let's not laser cut it.

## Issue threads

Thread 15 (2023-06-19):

Avoid pulling the entire list of user actions from the database when building config

delta-12, 2023-06-19:
Currently, every client configuration request pulls all actions associated with the client's user from the database.  There is likely a more efficient way of obtaining the actions associated with the client's devices.

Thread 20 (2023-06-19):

Fix string refs on frontend Devices page

delta-12, 2023-06-19:
The Devices page is producing the following warning:

Warning: A string ref, "users/<user uuid>/clients/<client uuid>/devices/<device uuid>/state/", has been found within a strict mode tree. String refs are a source of potential bugs and should be avoided. We recommend using useRef() or createRef() instead. Learn more about using refs safely here: https://reactjs.org/link/strict-mode-string-ref

delta-12, 2023-08-30:
Fix in commit `send commands to MQTT devices with protobufs`

Closed 2023-08-30.

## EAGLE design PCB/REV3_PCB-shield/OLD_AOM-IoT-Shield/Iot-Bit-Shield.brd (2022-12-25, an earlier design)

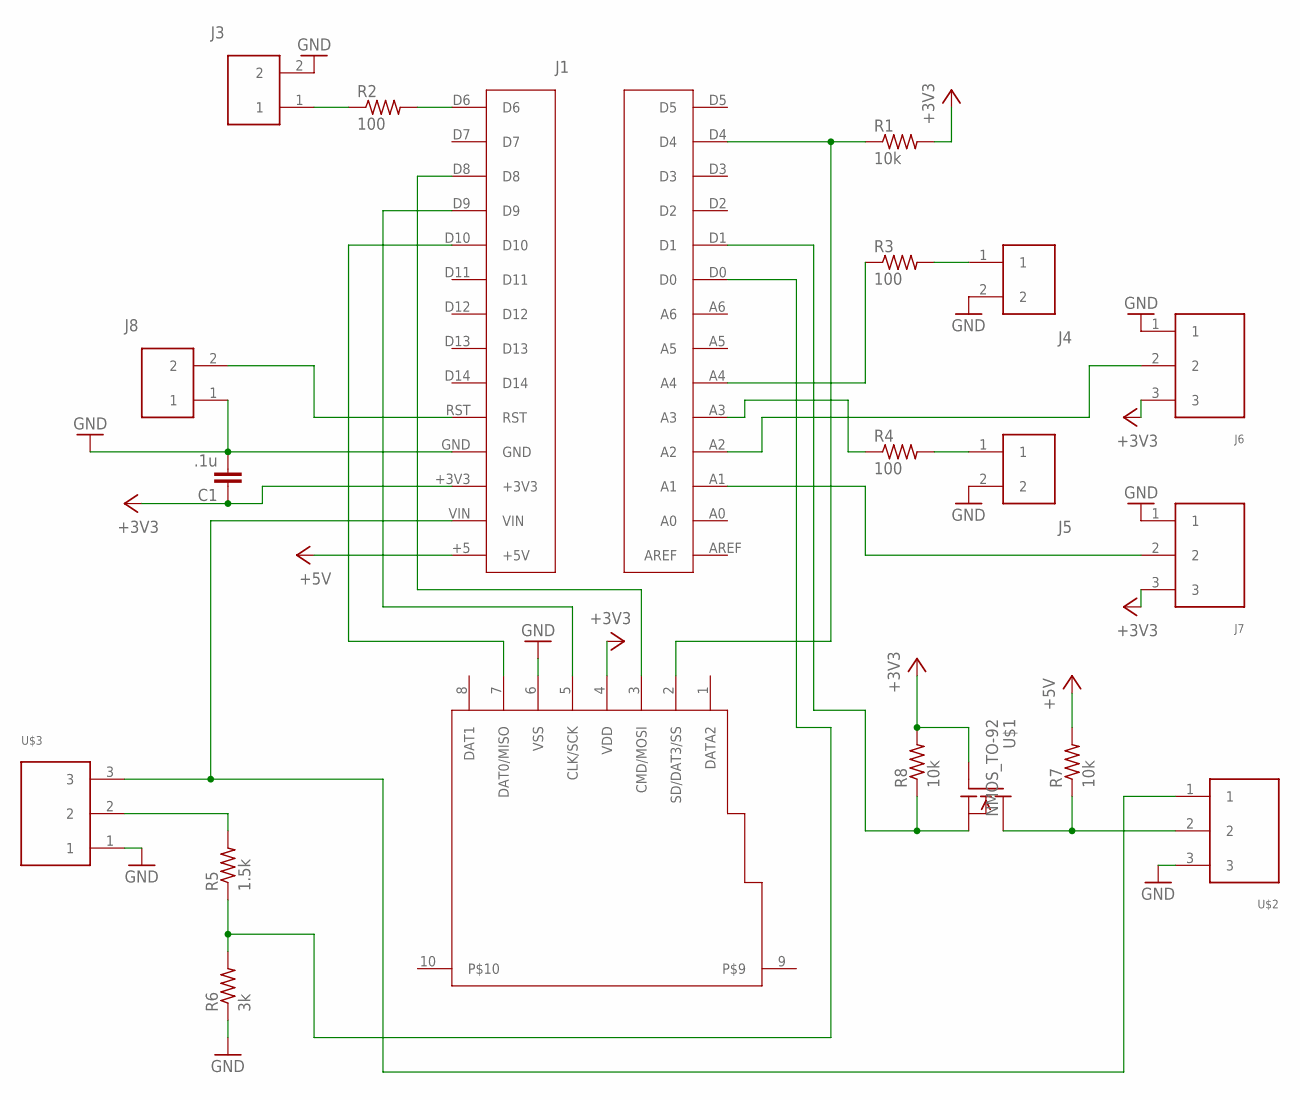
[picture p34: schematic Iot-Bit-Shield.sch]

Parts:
C1: .1u; C025-024X044
J1: MKR1010-HEADER-14POS; SIP-1X14
J2: 114-00841-68; AMPHENOL-SD-SMT
J3, J4, J5, J8: JST-PH-2POS-CONN-TH
J6, J7: JST-PH-3POS-CONN-TH
R1, R7, R8: 10k; RES-LARGE-PAD
R2, R3, R4: 100; RES-LARGE-PAD
R5: 1.5k; RES-LARGE-PAD
R6: 3k; 0204/5
U$1: NMOS_TO-92; TO-92
U$2, U$3: HEADER-2.54MM; 2.54MM-HEADER

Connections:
+3V3: C1.1, J1.+3V3, J2.4 (VDD), J6.3, J7.3, R1.2, R8.2, U$1.1 (G)
+5V: J1.+5 (+5V), R7.2
GND: C1.2, J1.GND, J2.6 (VSS), J3.2, J4.2, J5.2, J6.1, J7.1, J8.1, R6.1, U$2.3, U$3.1
unnamed: J1.D4, J2.2 (SD/DAT3/SS), R1.1
unnamed: J1.D8, J2.3 (CMD/MOSI)
unnamed: J1.D9, J2.5 (CLK/SCK)
unnamed: J1.D10, J2.7 (DAT0/MISO)
unnamed: J1.D6, R2.2
unnamed: J1.A4, R3.1
unnamed: J1.A3, R4.1
unnamed: J3.1, R2.1
unnamed: J4.1, R3.2
unnamed: J5.1, R4.2
unnamed: J1.A1, J7.2
unnamed: J1.A2, J6.2
unnamed: J1.RST, J8.2
unnamed: R7.1, U$1.2 (D), U$2.2
unnamed: J1.D0, R5.1, R6.2
unnamed: R5.2, U$3.2
unnamed: J1.VIN, U$2.1, U$3.3
unnamed: J1.D1, R8.1, U$1.3 (S)

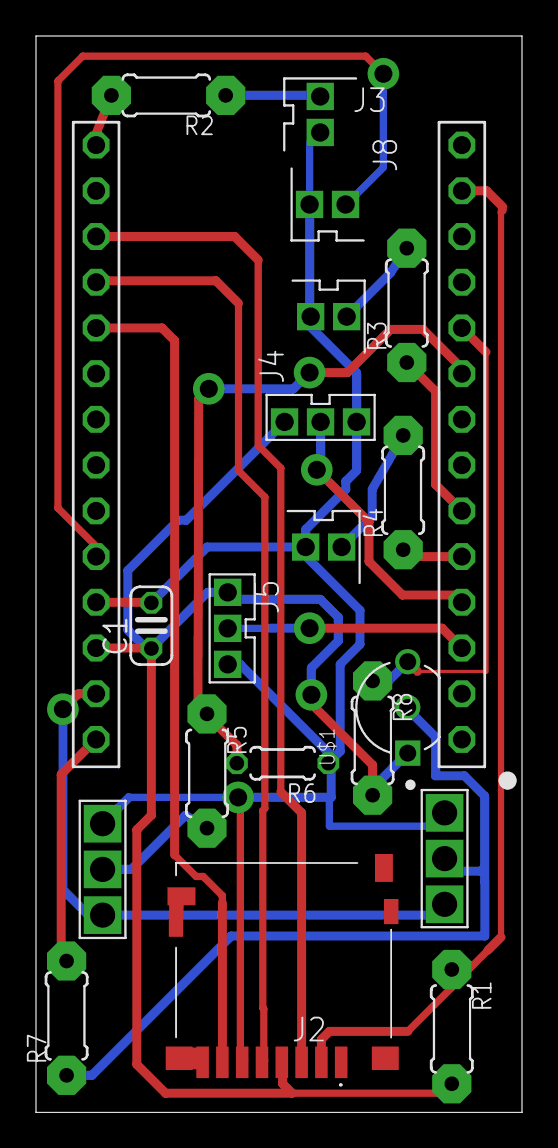
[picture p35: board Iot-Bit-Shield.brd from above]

Board: 2 copper layers, 27.0 x 59.8 mm, 20 parts (0 on the bottom side), 21 nets.

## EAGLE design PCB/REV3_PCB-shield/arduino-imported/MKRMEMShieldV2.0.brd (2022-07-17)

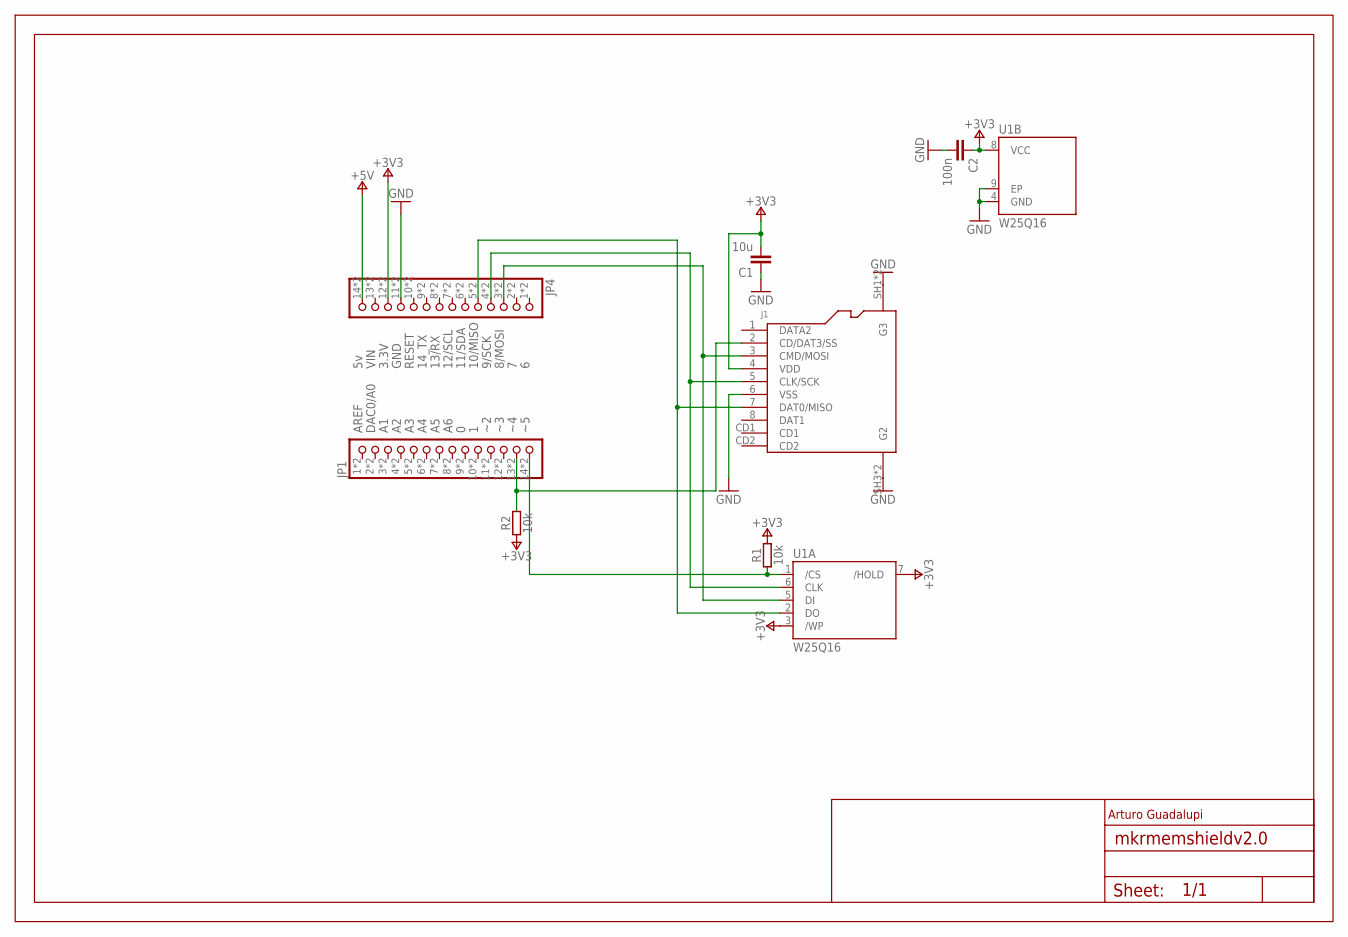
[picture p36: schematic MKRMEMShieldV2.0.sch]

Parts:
C1: 10u; 0603-1608X90N
C2: 100n; 0603-1608X90N
FRAME1: DNP; FRAME
J1: -; AMPHENOL_114-00841-68
JP1, JP4: -; 1X14-DOUBLE
R1, R2: 10k; C0603
U1: W25Q16; SON9P127_500X600X80L60X41T340X400N

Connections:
+3V3: C1.2, C2.1, J1.4 (VDD), JP4.12, JP4.26 (12), R1.2, R2.1, U1.3 (/WP), U1.7 (/HOLD), U1.8 (VCC)
+5V: JP4.14, JP4.28 (14)
GND: C1.1, C2.2, J1.6 (VSS), J1.SH1 (G3), J1.SH2 (G3), J1.SH3 (G2), J1.SH4 (G2), JP4.11, JP4.25 (11), U1.4 (GND), U1.9 (EP)
unnamed: JP1.14, JP1.28 (14), R1.1, U1.1 (/CS)
unnamed: J1.3 (CMD/MOSI), JP4.3, JP4.17 (3), U1.5 (DI)
unnamed: J1.5 (CLK/SCK), JP4.4, JP4.18 (4), U1.6 (CLK)
unnamed: J1.7 (DAT0/MISO), JP4.5, JP4.19 (5), U1.2 (DO)
unnamed: J1.2 (CD/DAT3/SS), JP1.13, JP1.27 (13), R2.2

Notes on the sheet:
AREF
DAC0/A0
8/MOSI
9/SCK
10/MISO
11/SDA
12/SCL
13/RX
14_TX
RESET
GND
3.3V
VIN
Arturo Guadalupi

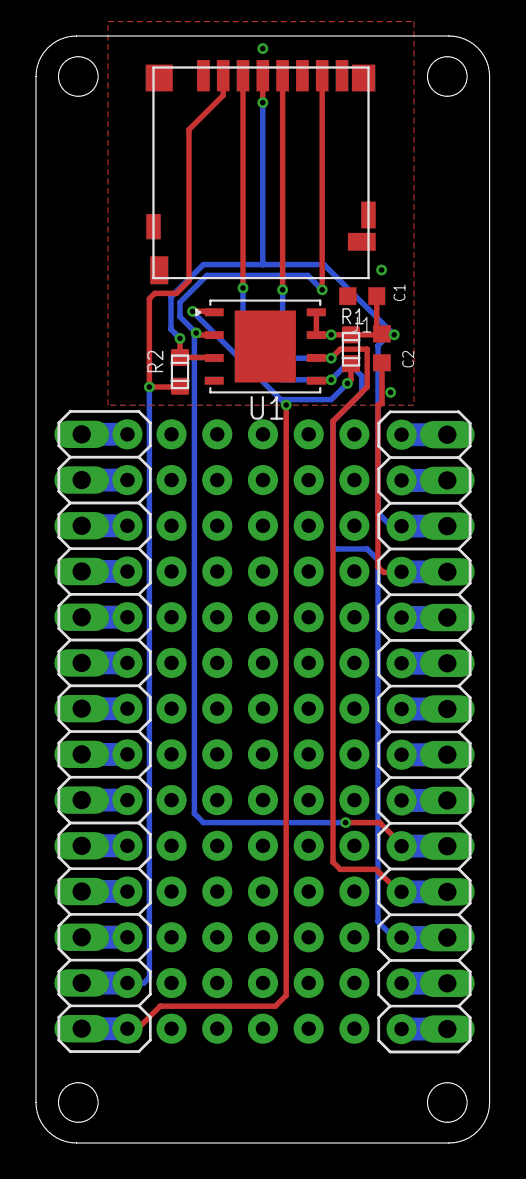
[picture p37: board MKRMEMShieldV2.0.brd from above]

Board: 2 copper layers, 25.2 x 61.5 mm, 9 parts (0 on the bottom side), 8 nets.

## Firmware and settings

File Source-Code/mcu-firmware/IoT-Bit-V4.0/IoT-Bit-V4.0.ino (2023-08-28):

/*
 * Authors: Mark Hofmeister, Issam Abushaban, Benjamin Esquieres
 * Created: 7/30/2022
 * Last Updated: 03/27/2023
 * Version: V4.0
 *
 */

#include "Wifi_Setup.h" // Header file for wifi setup functions
#include "pb_decode.h"
#include "controller_message.pb.h"
#include "AoM_IoT_devices.h"

/* SD card attached to SPI bus as follows, do not use these pins
 *  MOSI  - pin 11
 *  MISO  - pin 12
 *  CLK   - pin 13
 *  CS    - pin  4
 */

#define DEVICE_0_PIN 0
#define DEVICE_1_PIN 1

Device device0(DEVICE_0_PIN, 0); // Device 0 will be a digital input
Device device1(DEVICE_1_PIN, 1); // Device 1 will be a digital output

int pubSwitch = A1;  // The pin for reading the PUB switch status
int recvSwitch = A2; // The pin for reading the RECV switch status

int pubLED = A3;  // The pin for outputing the POST status to an LED
int recvLED = A6; // The pin for outputing the GET status to an LED

int wifiStatusLED = 6; // The pin for outputing the wifi connection status to an LED

unsigned long LEDDelayPeriod = 500;
unsigned long statusUpdatePeriod = 2000;
unsigned long statusUpdateNext = 0;

bool publish = false;

// Buffers for each device topic
#define MAX_TOPIC_SIZE 256
char device0ConfigTopic[MAX_TOPIC_SIZE];
char device0StateTopic[MAX_TOPIC_SIZE];
char device0CmdTopic[MAX_TOPIC_SIZE];
char device1ConfigTopic[MAX_TOPIC_SIZE];
char device1StateTopic[MAX_TOPIC_SIZE];
char device1CmdTopic[MAX_TOPIC_SIZE];

void setup()
{
  /* Begins Serial monitor for debugging purposes. */
  Serial.begin(9600);

  pinMode(pubSwitch, INPUT);
  pinMode(recvSwitch, INPUT);

  pinMode(wifiStatusLED, OUTPUT);
  pinMode(pubLED, OUTPUT);
  pinMode(recvLED, OUTPUT);

  /* Attempt to read from secrets.txt */
  do
  {
    for (int i = 0; i < 3; i++)
    {
      digitalWrite(recvLED, HIGH);
      digitalWrite(pubLED, HIGH);
      digitalWrite(wifiStatusLED, HIGH);
      delay(100);

      digitalWrite(recvLED, LOW);
      digitalWrite(pubLED, LOW);
      digitalWrite(wifiStatusLED, LOW);
      delay(100);
    }

    /* Wait 3 seconds before initializing */
    Serial.print("Checking For SD card in...");
    Serial.print("3...");
    delay(1000);
    Serial.print("2...");
    delay(1000);
    Serial.print("1...");
    delay(1000);
    Serial.println("0");
    delay(1000);
  } while (initializeCredentials() == false);

  /* Let them know that the device is ready */
  digitalWrite(recvLED, HIGH);
  digitalWrite(pubLED, HIGH);
  digitalWrite(wifiStatusLED, HIGH);
  delay(1000);
  digitalWrite(recvLED, LOW);
  digitalWrite(pubLED, LOW);
  digitalWrite(wifiStatusLED, LOW);
  delay(1000);
}

void loop()
{
  if (millis() > statusUpdateNext)
  {
    Serial.print("\nReceive Mode Switch: ");
    Serial.println(digitalRead(recvSwitch));
    Serial.print("Publish Mode Switch: ");
    Serial.println(digitalRead(pubSwitch));
    statusUpdateNext = millis() + statusUpdatePeriod;
  }

  if (!wifiConnected()) /* Determine if wifi connection needs to be restablished. */
  {
    /* Connection to WiFi terminated */
    digitalWrite(wifiStatusLED, LOW);
    digitalWrite(pubLED, LOW);
    digitalWrite(recvLED, LOW);

    /* Attempt to restablish connection */
    Serial.println("Initializing connection to WIFI...");
    if (connectToWIFI())
    {
      /* Connection to WiFi established */
      digitalWrite(wifiStatusLED, HIGH);
    }
  }
  else if (!pubSubClient.connected())
  {
    connectPubSubClient(callback);

    // Build device 0 topics
    buildTopic(clientUsername, DEVICE_0, CONFIG, device0ConfigTopic, MAX_TOPIC_SIZE);
    buildTopic(clientUsername, DEVICE_0, STATE, device0StateTopic, MAX_TOPIC_SIZE);
    buildTopic(clientUsername, DEVICE_0, CMD, device0CmdTopic, MAX_TOPIC_SIZE);

    // Build device 1 topics
    buildTopic(clientUsername, DEVICE_1, CONFIG, device1ConfigTopic, MAX_TOPIC_SIZE);
    buildTopic(clientUsername, DEVICE_1, STATE, device1StateTopic, MAX_TOPIC_SIZE);
    buildTopic(clientUsername, DEVICE_1, CMD, device1CmdTopic, MAX_TOPIC_SIZE);

    // Subscribe to config and cmd topics
    subscribePubSubClient(device0ConfigTopic);
    subscribePubSubClient(device0CmdTopic);
    subscribePubSubClient(device1ConfigTopic);
    subscribePubSubClient(device1CmdTopic);
  }
  else /* All other cases assume a connection to wifi. */
  {
    if (device0.enabled && device0.publish && digitalRead(pubSwitch) == HIGH)
    {
      // TODO publish device zero
      // Publish new state for device 1
      byte *payload = (byte *)&device0.value;
      if (pubSubClient.publish(device0StateTopic, payload, 4, true))
      {
        // Blink LED to indicate successful publish
        digitalWrite(recvLED, HIGH);
        delay(LEDDelayPeriod);
        digitalWrite(recvLED, LOW);
        delay(LEDDelayPeriod);
        device0.publish = false;
      }
      else
      {
        Serial.println("Failed to publish new state for device 0");
      }
    }

    pubSubClient.loop();
  }

  delay(250);
}

void callback(char *topic, byte *payload, unsigned int length)
{
  if (strcmp(topic, device0ConfigTopic) == 0 || strcmp(topic, device1ConfigTopic) == 0)
  {
    aom_iot_controller_ControllerMessage controllerMessage = aom_iot_controller_ControllerMessage_init_zero;
    pb_istream_t stream = pb_istream_from_buffer(payload, length);
    bool status = pb_decode(&stream, aom_iot_controller_ControllerMessage_fields, &controllerMessage);
    if (!status)
    {
      Serial.print("Failed to decode configuration for ");
      Serial.println(topic);
      Serial.print("Decoding error: ");
      Serial.println(PB_GET_ERROR(&stream));
    }
    else
    {
      if (controllerMessage.device.number == 0)
      {
        configureDevice(&device0, &controllerMessage, device0ISR);
      }
      if (controllerMessage.device.number == 1)
      {
        configureDevice(&device1, &controllerMessage, NULL);
      }
    }
  }

  /* Only update output if switch is enabled*/
  if (digitalRead(recvSwitch) == HIGH && strcmp(topic, device1CmdTopic) == 0)
  {
    // Set device 1 output
    uint32_t payloadValue = 0;
    for (unsigned int i = 0; i < length; i++)
    {
      payloadValue += *(payload + i) << (8 * i);
    }
    bool output = payloadValue;
    if (device1.enabled)
    {
      digitalWrite(device1.pin, output);
    }

    // Publish new state for device 1
    byte *newPayload = (byte *)&output;
    if (!pubSubClient.publish(device1StateTopic, newPayload, 1, true))
    {
      Serial.println("Failed to publish new state for device 1");
    }

    // Blink LED to indicate message successfully received
    digitalWrite(recvLED, HIGH);
    delay(LEDDelayPeriod);
    digitalWrite(recvLED, LOW);
    delay(LEDDelayPeriod);
  }
}

void device0ISR()
{
  device0.value = digitalRead(device0.pin);
  device0.publish = true;
}

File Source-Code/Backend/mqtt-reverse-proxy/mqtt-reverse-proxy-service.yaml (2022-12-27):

apiVersion: v1
kind: Service
metadata:
  name: mqtt-reverse-proxy-service
spec:
  type: LoadBalancer
  selector:
    app: mqtt-reverse-proxy
  ports:
    - name: mqtt
      protocol: TCP
      port: 1883
      targetPort: 1883
    - name: mqtt-websocket
      protocol: TCP
      port: 9001
      targetPort: 9001

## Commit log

2022-01-20 IOT BIT PROTOTYPE 1!!!!!
    With the turn of a potentiometer you can decide how frequently to Post/Poll data 🤩🤩🤩
    With the flick of 2!! Switches you can decide if you want to Post/Poll/Both/or Idle! ✨✨✨
    Wiring diagram will be uploaded soon!
2022-01-20 Reorganized File System
    [AOM_IoT_Bit.fzz]
2022-01-20 Diagram of V1.0 Done!
    [AOM_IoT_Bit.fzz]
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2022-01-24 Most up to date pins with board v1.1
    [AOM_IoT_Bit_V1.1.fzz]
2022-01-25 Added files, fixed bugs. SD reads strings in to ASCII.
    [AOM_IoT_Bit_V1.1.fzz, AOM_IoT_Bit_V2.0.fzz]
2022-01-27 YES!!!!
    I cannot believe how simple the fix was! I was using the SSID as the PASS!! 😜
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2022-01-28 Updated Diagrams
    [AOM_IoT_Bit_V2.0.fzz]
2022-01-28 Added housing v1
    [AoM-IoT-bit-Housing v11.stl]
2022-01-31 Added MKR Stl
    [Arduino_MKR_1000_long_pins.stl]
2022-01-31 Added top new
    [Top-Plate-v2.stl]
2022-01-31 Student Helped Us 😜
    [Wifi LittleBit Encasing Face (QuickPrint).stl, Wifi LittleBit Encasing Face.stl]
2022-02-02 Deleted spurious files
    [AoM-IoT-bit-Housing v1.stl, Wifi LittleBit Encasing Face (QuickPrint).stl, Wifi LittleBit Encasing Face.stl]
2022-02-04 Added housing v3
    [Base-v3.stl, Top-Plate-v3.stl]
2022-02-05 Added fixed base plate
    [Base-Plate-v4.stl]
2022-02-13 Adjusting Pins
    [AOM_IoT_Bit_V2.0.fzz]
2022-02-16 Updated fritzing schematic
    [AOM_IoT_Bit_V2.0.fzz]
2022-02-18 Confused 2
    [AOM_IoT_Bit_V2.0_Issam.fzz]
2022-03-06 Added updated CAD and media
    [Base-Plate-v4.stl, Base-Plate-v5.stl, Base-v3.stl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]
2022-03-09 Added more supplementary CAD
    [12mm x 12mm Tactile switch.obj, AOM_IoT_Bit_V2.0_Mark_LogicConverter.fzz, Base-Plate-v3.stl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]
2022-03-12 Added more media. New button .STEP file.
    [12mm x 12mm Tactile switch.obj, AoM-IoT-bit-Housing v1.stl, Button black standard.STEP]
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2022-07-17 Clean up old version-controlled revisions
    [AOM_IoT_Bit.fzz, AOM_IoT_Bit_V1.1.fzz, AOM_IoT_Bit_V2.0_Issam.fzz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]
2022-07-17 Revised fritzing schematic to 3.0
    [AOM_IoT_Bit.fzz, AOM_IoT_Bit_V1.1.fzz, AOM_IoT_Bit_V2.0_Issam.fzz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]
2022-07-17 New firmware rev
    [Base-Plate-v3.stl, Base-Plate-v4.stl, Base-Plate-v5.stl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]
2022-07-17 Fix fritzing drawing
    [AOM_IoT_Bit_V3.0.fzz, REV2-BOM.xlsx]
2022-07-17 Fix fritzing schematic 2
    [AOM_IoT_Bit_V3.0.fzz]
2022-07-30 Add prototype cycle 1 BOM
    [REV2-BOM-prototype-cyc1.xlsx, REV2-BOM.xlsx]
2022-07-30 Add code flowchart, add MOSFET to diagram, add post ISR
    [AOM_IoT_Bit_V3.0.fzz]
2022-07-31 Change swt/LED pinouts to accept interrupts, add ISRs to code
    [AOM_IoT_Bit_V3.0.fzz, REV2-BOM-prototype-cyc1.xlsx]
2022-07-31 Attach switch/LED interrupts
    [AOM_IoT_Bit_V3.0.fzz]
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2022-09-02 BOM digikey
    [REV2-BOM-prototype-cyc1-digiKey.xlsx]
2022-09-04 Breadboard update
    [AOM_IoT_Bit_V3.0.fzz]
2022-09-04 Interrupts for LEDs do not work'
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2022-09-05 blink LED function not working???
2022-09-07 Change to bi-directional logic level shifter - works.
    [AOM_IoT_Bit_V3.0.fzz, REV2-BOM-final-adafruit-haul.xlsx, REV2-BOM.xlsx]
2022-09-09 Add REV B of PCB. Don't want to lose.
    [Iot-Bit-Shield.brd, Iot-Bit-Shield.sch]
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2022-09-12 For wiring pruposes, changed get status LED to A6, swapped post and get data pins
    [Top-Plate-v4.stl, Top-plate-v6.stl]
2022-09-12 Update breadboard to refelect pivot to SD shield
    [AOM_IoT_Bit_V3.0.fzz]
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2022-11-01 Move BOMs to folder
    [REV2-BOM-final-adafruit-haul.xlsx, REV2-BOM-prototype-cyc1-digiKey.xlsx, REV2-BOM-prototype-cyc1.xlsx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]
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2022-12-24 controller kubernetes deployment
    [controller-deployment.yaml, controller-service.yaml]
2022-12-24 mqtt reverse proxy kubernetes deployment
    [mqtt-reverse-proxy-service.yaml]
2022-12-27 temp fix to avoid async ngx.fetch() in parser
    [mqtt-reverse-proxy-service.yaml]
2023-01-01 attach mqtt client to broker for monitoring
2023-01-06 add redis cache for mqtt server status
    [controller-deployment.yaml]
2023-01-09 Add media, migrate PCB work from Altium to Eagle. Creating new branch for PCB work
    [ABX00012.SchLib, ARDUINO_ABX00012.PcbLib, AoM-IoT-Bit-Shield.PrjPcb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]
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2023-01-09 Add Altium stuff to .gitignore
    [ABX00012.SchLib, AOM_IoT_Bit_V3.0.fzz, ARDUINO_ABX00012.PcbLib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]
2023-01-09 Add all .intlib except for JST connectors
    [AoM-IoT-Bit-Shield.PrjPcb, SD-shield.SchDoc]
2023-01-10 finish schematic capture of PCB. fritzing is all screwed up - refer to altium schematic
    [AOM_IoT_Bit_V3.0.fzz, AoM-IoT-Bit-Shield.PrjPcb, SD-shield.SchDoc]
2023-01-10 refactor mqtt-controller to work with new db schemas and rabbitmq
    [controller-deployment.yaml, controller-service.yaml]
2023-01-10 replace npn with mosfet, update user guide to V2.1
2023-01-12 Finish PCB routing.
    [AoM-IoT-Bit-Shield-v1.0.PcbDoc, AoM-IoT-Bit-Shield.PrjPcb, SD-shield.SchDoc]
2023-01-14 Finish PCB, ordered. Also update CAD models
    [3-641211-3.SchLib, AoM-IoT-Bit-Shield-v1.0-BOM.csv, AoM-IoT-Bit-Shield-v1.0.PcbDoc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]
2023-01-15 load MONGOURI from kubernetes secret
    [controller-deployment.yaml]
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2023-01-20 V3.1: Decrease SD card read delay. Automatically connect to WiFi regardless of switch state. Remove blinkLED function and replace with digitalWrites for now.
2023-01-24 Fix text bench. v1.0 --> v1.1
    [IoT-Bit-test-bench-v1.1.ino]
2023-02-03 Add updated Guide, picture. Begin REV3 BOM
    [BOM-full.xlsx, REV2-BOM.xlsx]
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2023-02-14 mqtt-controller redesign
    [controller-deployment.yaml, mqtt-controller-comms-deployment.yaml, mqtt-controller-comms-service.yaml]
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2023-02-21 fix publishing device configs with no actions
2023-02-21 cluster of 3 mqtt-controllers
    [controller-deployment.yaml]
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2023-02-25 Add completed REV3 BOM
    [BOM-full.xlsx, REV2-BOM.xlsx]
2023-02-25 Add .csv file for GH viewing
    [BOM-full.csv]
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2023-03-10 enable cors on mqtt controller
    [controller-deployment.yaml, controller-service.yaml]
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2023-03-20 apply permissions for mqtt-controller to interact with kubernetes
    [controller-cluster-role.yaml, controller-deployment.yaml]
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2023-08-28 Create REV 4 PCB file
    [3-641211-3.SchLib, AoM-IoT-Bit-Shield-v1.0-BOM.csv, AoM-IoT-Bit-Shield-v1.0.PcbDoc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]
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

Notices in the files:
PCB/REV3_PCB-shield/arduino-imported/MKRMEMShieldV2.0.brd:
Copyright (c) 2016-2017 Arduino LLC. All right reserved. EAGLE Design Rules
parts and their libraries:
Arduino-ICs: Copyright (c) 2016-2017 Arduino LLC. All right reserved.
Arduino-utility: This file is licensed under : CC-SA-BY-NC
